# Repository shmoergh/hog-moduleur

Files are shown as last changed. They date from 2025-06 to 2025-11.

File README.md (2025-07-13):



# Hog Moduleur

Fully analog DIY-friendly modular synth. Project is under development.

Follow the progress on [shmoergh.com](https://www.shmoergh.com/hog-moduleur/) — consider [subscribing to the newsletter](https://www.shmoergh.com/hog-moduleur/#/portal/signup) to get the latest updates in your inbox.



## Modules

- [00 — Eurorack frame](https://github.com/shmoergh/hog-moduleur/tree/main/00-eurorack-frame)
- [01 — Power supply](https://github.com/shmoergh/hog-moduleur/tree/main/01-psu)

## License

Shmøergh Hog Moduleur © 2024

Hardware is licensed under [CC BY-NC 4.0](https://creativecommons.org/licenses/by-nc/4.0/)

Software is licensed under [MIT](https://opensource.org/license/mit).

Font used on PCBs: https://departuremono.com

Simulations made in [CircuitJS](https://www.falstad.com/circuit/circuitjs.html)

## Disclaimer

All electronic projects and designs presented on this web site, or associated web sites should be considered dangerous if not lethal if not used safely. When working on projects based on the designs on this site, use extreme care to ensure that you do not come into contact with mains AC voltages or high voltage DC. If you are not confident about working with mains voltages, or high voltages, or you are not legally allowed to work with mains voltages, or high voltages, you are advised not to attempt work on them. The author, host, and all people associated with these web pages disclaim any liability for damages should anyone be killed or injured while working on these projects, or projects based on these designs, or any other project or design presented on these web pages and any associated web pages. The author, host, and all people associated with these web pages also disclaim any liability for projects, or projects based on these designs, or any other project or design presented on these web pages and any associated web pages when used in such a way as to infringe relevant government regulations and by-laws.

All circuits, schematics, printed circuit board, panel design and associated data published on this site can be used for private use only.

We are not responsible for any errors in the PCB design or the parts list. All responsibility for ordering PCBs, components, and assembly services rests solely with you.

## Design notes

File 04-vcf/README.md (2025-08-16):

# Hog Moduleur / VCF

Dual mode Eurorack compatible diode filter based on the famous Synthacon Steiner-Parker circuit.

## Features

- Classic diode filter with extremely drippy character
- Low pass and high pass filter inputs
- Fine-tunable maximum resonance control — can go smooth to crazy
- Two external CV inputs with logarithmic attenuverters
- Optional EMC shielding to isolate external noise
- Separate core and UI PCBs for reusability and custom UI builds
- Gerber files for JLCPCB order
- Designed from very common electronic components

## Photos


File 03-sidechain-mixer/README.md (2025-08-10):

# Hog Moduleur / Sidechain Mixer

4 channel Eurorack compatible mixer and sidechain compressor.

## Features

- 4 input audio or CV mixer (DC coupled)
- Channel 4 can be used as the control input for a VCA based sidechain compressor that acts on the output mix. Channel 4 can be individually added to the output mix or can remain silent, while the compressor still operates.
- Gain control for channel 4 which allows to amplify line level signals to Eurorack level, allowing to mix external instruments with Eurorack sound sources
- Dedicated output volume control
- Separate core and UI PCBs for reusability and custom UI builds
- Gerber files for JLCPCB order
- Designed from very common electronic components

## Status

**MODULE IS IN EXPERIMENTAL STATE! ASSUME WEIRD BEHAVIORS** 

More info in KiCad files.

## Photos



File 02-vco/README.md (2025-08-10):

# Hog Moduleur / VCO

Eurorack compatible VCO.

## Features

- Raw saw generator with classic waveshaper circuits. Triangle, saw and square outputs
- Sub oscillator and noise circuit (can be selected with a jumper)
- Pulse width voltage control for square wave
- High precision over about 10 octaves
- Hard sync input
- FM input
- Two temperature compensation options for flexible DIY build (one is THT only)
- Separate core and UI PCBs for reusability and custom UI builds
- Gerber files for JLCPCB order
- Designed from very common electronic components

## Photos



**IN PROGRESS**

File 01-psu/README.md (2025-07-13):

# Hog Moduleur / PSU – ±12V Eurorack Power Supply

This is the power supply unit for the Hog Moduleur, but it can be used in any Eurorack setup.

## 🐷 Features

- ±12V power. Works with any of the following Mean Well regulators:
    - [NSD10-12D12](https://mou.sr/3ZpECrS)
    - [DKM10A-12](https://mou.sr/450kLTV)
    - [DKMW20F-12](https://mou.sr/44G5aaH)
    - [DKMW30F-12](https://mou.sr/450gwaT)
- Requires **center positive** 12V DC input
- Breakable board: PSU and connector section can be separated (cut) for flexible mounting
- Built in DC barrel jack input and power switch
- Optional +/- input headers for off-board DC & switch placement. Just make sure you know what you're doing if you're using it.
- Designed for small Eurorack cases and standalone synth builds. Output current depends on the regulator used (see above).
- Open source hardware

## 🛠️ How to Build

- Gerber files for JLCPCB ordering are in the [`electronics/production`](./electronics/production) folder
- BOM is also in the [`electronics/production`](./electronics/production) folder. All components are available at Mouser
- Use the KiCad schematic and PCB layout for soldering reference
- **Before connecting any modules**, always measure the output voltages to confirm ±12V is stable

⚠️ This is a DIY-friendly project but assumes you know how to solder, read schematics, and handle basic electronics safely.

## 📷 Photos

CleanShot 2025-07-13 at 12 34 50@2x



## 🧪 License

Open source licensed under [CC BY-NC 4.0](https://creativecommons.org/licenses/by-nc/4.0/).

Feel free to fork, build, and tweak.

[Disclaimer](https://github.com/shmoergh/hog-moduleur)

---

🐖 [Shmøergh](https://shmoergh.com) — Fucking cool electronic instruments from Budaørs, HU.

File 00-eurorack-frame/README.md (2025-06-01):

# Hog Moduleur / Eurorack Frame

Extensible, 3D printable enclosure/frame designed for synth development in Eurorack format. 

## Components

1. **Rail** — designed to be parametric, meaning that you can print it in any length just by adjusting the Y dimension in the 3D slicer software. It accepts standard M3 square nuts and M3x8 bolts.
2. **Connector** — join the stands to the rails vertically, and they also link rails to each other horizontally.
3. **Stands** — slanted at a 10° angle. Since they are not permanently coupled with the rails, it's easy to design and swap in other stand styles (e.g. flat) if needed.



## Assembly

No extra hardware is needed for full assembly.

1. Slide connectors to upper and lower slots of first stand
2. Slide in rails to first stand
3. Connect second stand and rails with connectors 



eurorack-frame-24hp

Default width of the rails is 24HP but it can be set directly in the slicer. Once we need more space it'll be very easy to extend the system to 48HP and further, just by offsetting the connectors and attaching new rails and stands.

eurorack-frame-48hp

## Printing instructions

When printing any of these components, choose the sides as the base in your slicer app. This allows printing without support which results in a much cleaner and stronger print, plus you can change the width (height) of the components as you wish, directly in the slicer.

CleanShot-2025-05-25-at-18 59 58@2x

## Mounting Eurorack modules

The rails welcome standard M3 square nuts and you can use M3x8 screws to mount max 2mm thick panels. Use M3x10 screws for thicker panels.

## Photos




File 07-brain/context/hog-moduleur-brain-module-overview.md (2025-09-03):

# Hog Moduleur "Brain" module

## About

We're building a module for a synthesizer, called Brain. It is a universal digital module in a Eurorack synthesizer with multipurpose inputs and outputs which allows users to write their own firmware. Additionally we're going to provide some basic modules and probably an SDK for it so that it's easy to get started.

## Features

Brain is based on the Raspberry Pi Pico. It's a universal digital module for Eurorack synths with flexible inputs and outputs.
- 2 analog inputs for CV and audio signals using 2 of the the Pico's ADCs
- 2 analog outputs which uses an MCP4822 DAC. The output of the DAC can be programmatically AC or DC coupled, using a CD4053 IC.
- 1 pulse input, using digital GPIO, preceded by a transistor switch (for safety)
- 1 pulse output, using digital GPIO with a simple transistor switch
- 1 dedicated MIDI input. This input is not universal because MIDI requires special input circuitry

Additionally there are some controls on the UI:
- 3 potmeters, multiplexed, using the third ADC of the Pico
- 2 pushbuttons
- 6 LEDs. The power for the LEDs are taken from the external power supply (using transistors) because of the Pico's limited power capabilities. The LEDs brightness can be set with PWM output from the Pico

As the Pico and Pico2 are pin compatible, the newer version can be used for heavier programs like effects or DSP.

## Code

Code can be flashed to the Pico using the normal procedure of holding the dedicated button while plugging the pico in a computer. Then the Pico appears as a drive which can accept firmware files.

## Factory programs

The first (default) factory program will be a MIDI to CV converter, as the rest of the synth works with control voltage. Later we'll work on a sequencer/arpeggiator, delay or reverb, external sound sources, basic drum machine and so on.

The factory programs are all written in C++ using the Pico SDK.

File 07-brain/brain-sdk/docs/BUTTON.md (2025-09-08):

# BUTTON Component

## Overview
The BUTTON component provides an interface for pushbutton inputs in the Hog Moduleur Brain module. It handles debouncing, state tracking, and event callbacks for button presses and releases.

## Features
- Debounced button input using Pico GPIO
- Event-driven: supports callbacks for press/release
- Polling via `update()` method for main loop integration
- Configurable for different GPIO pins

## Usage
1. **Initialization**: Create a `Button` instance, specifying the GPIO pin.
2. **Polling**: Call `update()` regularly in your main loop.
3. **Callbacks**: Register callback functions for press/release events.

## Example
```cpp
#include "brain-ui/button.h"

brain::ui::Button myButton(5); // GPIO 5
myButton.setPressCallback([](){
    // Handle press
});
myButton.setReleaseCallback([](){
    // Handle release
});

while (true) {
    myButton.update();
    // ...other code...
}
```

## Notes
- Designed for use with mechanical pushbuttons.
- Debounce logic is optimized for embedded use.
- Avoid long operations in callbacks.

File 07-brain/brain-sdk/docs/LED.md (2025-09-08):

# LED Component

## Overview
The LED component manages individual LEDs in the Hog Moduleur Brain module, supporting brightness control via PWM and event-driven blinking.

## Features
- Controls LED state (on/off)
- Adjustable brightness using Pico PWM
- Supports blinking with configurable duration
- Event callback for blink completion

## Usage
1. **Initialization**: Create an `Led` instance, specifying the GPIO pin and PWM channel.
2. **Control**: Use methods to set brightness, turn on/off, or start a blink.
3. **Polling**: Call `update()` in the main loop for blink timing.
4. **Callbacks**: Register a callback for blink completion if needed.

## Example
```cpp
#include "brain-ui/led.h"

brain::ui::Led statusLed(10, 2); // GPIO 10, PWM slice 2
statusLed.setBrightness(128); // 50% brightness
statusLed.blink(500); // Blink for 500 ms
statusLed.setBlinkCallback([](){
    // Blink finished
});

while (true) {
    statusLed.update();
}
```

## Notes
- Designed for transistor-driven LEDs (Eurorack compatible)
- Avoid blocking operations in callbacks
- Multiple LEDs can be managed independently

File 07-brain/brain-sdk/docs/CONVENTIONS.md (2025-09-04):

# Brain SDK – C/C++ Conventions (Google Style, Embedded-friendly)

> Scope: All code in `brain-sdk/` (`lib/*`, `programs/*`).
> Baseline: Google C++ Style Guide (naming, formatting, includes) with embedded tweaks.

---

## 0) TL;DR Checklist
- 4-space indent, max 100 cols, UTF-8, Unix newlines.
- Filenames: `lower_case_with_underscores.{h,cc,cpp}`.
- Folder names: `kebab-case` (e.g., `brain-io`, `brain-dsp`).
- Types/classes/enums: `PascalCase`.
- Functions: `PascalCase`.
- Variables: `lower_case_with_underscores`; class members end with `_`.
- Constants: `kPascalCase`.
- Macros: `ALL_CAPS_WITH_UNDERSCORES` (avoid; prefer `constexpr`/`enum`).
- No exceptions, no RTTI by default. No dynamic allocation in ISRs.
- `const` and `constexpr` aggressively. Prefer `enum class` over `#define`.
- One `#include` per line. Order: C system → C++ std → third-party → project.
- Headers are self-contained & guarded. `.cc/.cpp` mirrors header order.
- Public APIs documented with brief Doxygen comments.

---

## 1) File Layout & Naming
- **Folders**: use kebab-case → `lib/brain-io/`, `lib/brain-dsp/`.
- **Files**: `lower_case_with_underscores.h` / `.cc` (or `.cpp`).
- **One module per pair**: `brain-io/gpio_driver.h` ↔ `brain-io/gpio_driver.cc`.
- **No mega-files**: prefer small, testable units.

**Header guard** (prefer `#pragma once` for brevity):
```cpp
#pragma once
// or, if guards required:
// #ifndef BRAIN_IO_GPIO_DRIVER_H_
// #define BRAIN_IO_GPIO_DRIVER_H_
// ...
// #endif  // BRAIN_IO_GPIO_DRIVER_H_
```

---

## 2) Includes & Dependencies
Order in both headers and sources:
1. C system headers (`<stdint.h>`, `<stddef.h>`)
2. C++ standard (`<array>`, `<span>`, `<optional>`)
3. Pico/3rd-party (`<pico/stdlib.h>`, `hardware/gpio.h`)
4. Project headers (`"brain-io/gpio_driver.h"`)

One include per line; no wildcard includes. Prefer forward declarations in headers where possible.

---

## 3) Formatting
- **Indent**: 4 spaces; **Line length**: 100.
- **Braces**: K&R style.
```cpp
if (ready) {
	DoThing();
} else {
  	HandleError();
}
```
- **Namespace**: wrap entire file; avoid anonymous namespaces in headers.
```cpp
namespace brain::io {
// ...
}  // namespace brain::io
```

---

## 4) Naming
- **Namespaces**: `lower_case` (e.g., `brain::io`).
- **Types / Classes / Structs / Enums**: `PascalCase` (e.g., `AdcSampler`).
- **Functions & Methods**: `PascalCase` (e.g., `Init()`, `ReadChannel()`).
- **Variables**: `lower_case_with_underscores` (`sample_rate_hz`).
  - **Data members**: `trailing_underscore_` (e.g., `gpio_`).
- **Constants**: `kPascalCase` (`kMaxChannels`).
- **Macros**: `ALL_CAPS_WITH_UNDERSCORES` (use sparingly).
- **Aliases**: `using Sample = uint16_t;` (avoid `typedef` in new code).

---

## 5) Language Use
### C++
- **C++17+** (or project default). Prefer `<array>`, `<span>`, `<optional>`, `<chrono>`.
- **No exceptions / no RTTI** by default (size & determinism). Use `Status` returns.
- Prefer **`enum class`**; avoid unscoped enums.
- Prefer **`constexpr`** & **`const`** over macros; **`static`** for internal linkage.
- RAII for HW resources when feasible (GPIO claim/release), but keep ISRs free of heavy constructs.

### C (when used)
- Follow same formatting; `snake_case` for functions/vars is acceptable in pure-C modules.
- Use fixed-width integers from `<stdint.h>`.

---

## 6) APIs & Headers
- Headers are **self-contained** (compile on their own).
- Forward-declare where practical; don’t `#include` what you don’t use.
- Public API gets a brief Doxygen block:
```cpp
/// Samples N channels via a 74HC4051 into the Pico ADC.
/// Blocking; ~200 µs per channel typical.
/// @param channels logical channel indices [0..2]
/// @return last sampled value in 12-bit right-aligned format.
uint16_t SampleOnce(int channel);
```

---

## 7) Error Handling & Logging
- Return `bool` / small `Status` enums for expected errors; no exceptions.
- For fatal HW config errors in bring-up/demo code, `assert()` is acceptable (not in library hot paths).
- Logging:
  - Default to **UART stdio** (`pico_enable_stdio_uart(... 1)`).
  - Use minimal `fprintf(stderr, ...)`/`printf()` in libraries; let programs decide verbosity.

---

## 8) Embedded Rules (Pico/RP2040)
- **ISRs**: `static inline` where sensible; **no malloc/new**, no `printf`, keep <50 µs.
- **Volatile** only for MMIO or truly shared flags; pair with memory barriers when needed.
- **Concurrency**: prefer RP2040 primitives (IRQ disable windows, multicore queues, spinlocks) with brief critical sections.
- **Timing**: use `absolute_time_t` / `busy_wait_us()` from pico-time; avoid ad-hoc loops.
- **GPIO**: configure once in init; document pin ownership in module comments.
- **DMA/PWM/ADC**: place registers/config in one module; avoid cross-module control.

---

## 9) Tests & Examples
- Unit tests for pure logic (host-buildable) go under `tests/` (future).
- Hardware demos live in `programs/<name>/`.
- Keep examples tiny: one concept per example.

---

## 10) CMake Conventions
- Targets mirror file names: `brain-io`, `adc-sampler`, etc.
- Libraries default to **`INTERFACE`** if header-only; otherwise `STATIC`.
- All executables link `pico_stdlib` and only the libs they need.
- Stdio defaults (for picoprobe):
  ```cmake
  pico_enable_stdio_usb(<target> 0)
  pico_enable_stdio_uart(<target> 1)
  ```
- Add UF2 outputs:
  ```cmake
  pico_add_extra_outputs(<target>)
  ```

---

## 11) Comments & Documentation
- Prefer short, clear comments explaining *why*, not *what*.
- File header (top 6 lines): one-sentence purpose, dependencies, hardware notes, author/owner.
- Use Doxygen for public APIs; keep private helpers undocumented unless non-obvious.

---

## 12) Sample Skeleton

```cpp
// adc-sampler.h
#pragma once
#include <cstdint>
namespace brain::io {

class AdcSampler {
 public:
  bool Init();                   // config ADC + mux GPIOs
  uint16_t SampleChannel(int channel);  // 0..2

 private:
  void SelectMux(int channel);
  uint16_t ReadAdcOnce();

  int adc_channel_ = 0;
};

}  // namespace brain::io
```

```cpp
// adc-sampler.cc
#include "brain-io/adc-sampler.h"
#include "pico/stdlib.h"
#include "hardware/adc.h"

namespace brain::io {

bool AdcSampler::Init() {
  adc_init();
  // configure GPIOs, etc.
  return true;
}

uint16_t AdcSampler::SampleChannel(int channel) {
  SelectMux(channel);
  sleep_us(10);     // settle
  (void)ReadAdcOnce(); // throw-away
  return ReadAdcOnce();
}

void AdcSampler::SelectMux(int channel) {
  // drive S0/S1, keep S2 low
}

uint16_t AdcSampler::ReadAdcOnce() {
  return adc_read();
}

}  // namespace brain::io
```

---

## 13) Things to Avoid
- Global mutable state (except tightly-scoped singletons for HW where necessary).
- Hidden work in constructors; prefer `Init()` returning `bool`.
- Long lambdas or templates in embedded hot paths (code size bloat).
- Overuse of macros; prefer `constexpr`, `inline`, and typed enums.

---

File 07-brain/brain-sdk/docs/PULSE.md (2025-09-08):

# PULSE Component

## Overview
The PULSE component provides digital pulse input and output handling for the Hog Moduleur Brain module. It supports edge detection, debouncing, and event callbacks for pulse events.

## Features
- Handles pulse input (e.g., clock, trigger) via GPIO
- Supports pulse output (e.g., gate, trigger)
- Edge detection (rising/falling)
- Debounce logic for input pulses
- Event-driven: callbacks for pulse events

## Usage
1. **Initialization**: Create a `Pulse` instance, specifying the GPIO pin and direction (input/output).
2. **Polling**: Call `update()` in the main loop for input edge detection.
3. **Control**: For output, use methods to set or trigger pulses.
4. **Callbacks**: Register callbacks for pulse events (input only).

## Example
```cpp
#include "brain-io/pulse.h"

brain::io::Pulse clockIn(6, true); // GPIO 6, input
clockIn.setRisingCallback([](){
    // Clock pulse detected
});

brain::io::Pulse gateOut(7, false); // GPIO 7, output
gateOut.trigger(); // Send pulse

while (true) {
    clockIn.update();
}
```

## Notes
- Designed for Eurorack pulse signals (5V logic)
- Debounce logic is optimized for fast clocks
- Avoid blocking operations in callbacks

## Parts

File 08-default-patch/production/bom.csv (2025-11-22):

Designator | Footprint | Quantity | Value | LCSC Part #
JP1, JP10, JP11, JP12, JP13, JP2, JP3, JP4, JP5, JP6, JP7, JP8, JP9 | SolderJumper-2_P1.3mm_Bridged_RoundedPad1.0x1.5mm | 13 | Jumper_2_Bridged
J_ENV_VCA1, J_ENV_VCA2, J_FILTER1, J_MIXER1, J_UTILS_OUT1 | PinHeader_2x06_P2.54mm_Vertical | 5 | Conn_01x06
J_VCO1, J_VCO2 | PinHeader_2x07_P2.54mm_Vertical | 2 | Conn_01x07

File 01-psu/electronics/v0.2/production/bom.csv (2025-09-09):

Designator | Footprint | Quantity | Value | LCSC Part #
D1, D3, D4 | LED_D3.0mm | 3 | LED
D2 | D_DO-41_SOD81_P7.62mm_Horizontal | 1 | 1N4001
IC1 | Converter_DCDC_MeanWell_NSD10_DKMW_THT | 1 | ISOLATED_DC-DC_CONV
J1 | BarrelJack_Wuerth_6941xx301002 | 1 | Barrel_Jack_Switch
J2, J3, J4, J5 | IDC-Header_2x08_P2.54mm_Horizontal | 4 | Conn_02x08_Odd_Even
R1, R2, R3 | R_Axial_DIN0207_L6.3mm_D2.5mm_P7.62mm_Horizontal | 3 | 1k
S1 | SW_PB400EEQR1BLK | 1 | PB400EEQR1BLK

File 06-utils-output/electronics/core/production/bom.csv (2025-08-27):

Designator | Footprint | Quantity | Value | LCSC Part #
C1, C10, C11, C12, C13, C2, C3, C4, C5, C6 | 0603 | 10 | 100n | C14663
C14 | CP_Elec_5x5.4 | 1 | 10u | C4747971
C15 | 0603 | 1 | 100p | C14858
C16, C17 | C_Rect_L7.2mm_W2.5mm_P5.00mm_FKS2_FKP2_MKS2_MKP2 | 2 | 100n (foil)
C18 | C_Rect_L7.2mm_W2.5mm_P5.00mm_FKS2_FKP2_MKS2_MKP2 | 1 | 1n (foil)
C7 | C_Rect_L7.0mm_W2.5mm_P5.00mm | 1 | 22n-47n (foil)
C8, C9 | CP_Elec_6.3x7.7 | 2 | 100u | C2836437
D1, D2 | D_SOD-323 | 2 | 1N5817 | C5190152
D15, D16, D3, D4 | D_SOD-123 | 4 | 1N4148 | C81598
D_LIM_N1 | LED_D3.0mm | 1 | Red LED
D_LIM_P1 | LED_D5.0mm | 1 | Red LED
J1 | PinHeader_2x06_P2.54mm_Vertical | 1 | Conn_02x06_Odd_Even
J2 | PinHeader_2x03_P2.54mm_Vertical | 1 | Conn_02x03_Odd_Even
J3 | PinHeader_1x02_P2.54mm_Vertical | 1 | Conn_01x02
J4 | PinHeader_2x04_P2.54mm_Vertical | 1 | Conn_02x04_Odd_Even
J5 | PinHeader_2x02_P2.54mm_Vertical | 1 | Conn_02x02_Odd_Even
J6 | PinHeader_2x05_P2.54mm_Vertical | 1 | Conn_02x05_Odd_Even
J7 | IDC-Header_2x05_P2.54mm_Horizontal | 1 | Conn_02x05_Odd_Even
Q2 | TO-92_Inline_Wide | 1 | 2N3819
Q4 | SOT-23 | 1 | BC848 | C458985
R1 | 0603 | 1 | 33k | C4216
R10, R18, R26, R27, R29, R7 | 0603 | 6 | 10k | C25804
R11, R20 | 0603 | 2 | 4.7k | C23162
R12 | 0603 | 1 | 150 | C22808
R13, R17, R25, R28, R30 | 0603 | 5 | 1k | C21190
R14, R15 | 0603 | 2 | 100 | C22775
R16 | 0603 | 1 | 1M | C22935
R19, R2, R21, R22, R23, R3, R4, R5, R6 | 0603 | 9 | 100k | C25803
R24 | 0603 | 1 | 22k | C31850
R8, R9 | 0603 | 2 | 47k | C25819
RV_HEADPHONE_LIM1 | Potentiometer_ACP_CA6-H2,5_Horizontal | 1 | 100k
RV_LINE_OUT_LVL1 | Potentiometer_ACP_CA6-H2,5_Horizontal | 1 | 10k
U1, U2, U3, U5 | SOIC-8_3.9x4.9mm_P1.27mm | 4 | TL072 | C6961
U4 | SOIC-8_3.9x4.9mm_P1.27mm | 1 | NE5532 | C7426

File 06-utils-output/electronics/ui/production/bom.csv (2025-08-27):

Designator | Footprint | Quantity | Value | LCSC Part #
D1 | D_SMA | 1 | SMAJ5.0CA
D_DRIVE1, D_LFO1 | LED_D3.0mm | 2 | Red LED
D_DRIVE_FROM_CORE1 | PinSocket_1x02_P2.54mm_Vertical | 1 | Red LED
J1 | PinSocket_2x03_P2.54mm_Vertical | 1 | Conn_02x03_Odd_Even
J2 | PinSocket_2x04_P2.54mm_Vertical | 1 | Conn_02x04_Odd_Even
J3 | PinSocket_2x02_P2.54mm_Vertical | 1 | Conn_02x02_Odd_Even
J4 | PinSocket_1x02_P2.54mm_Vertical | 1 | Conn_01x02
J5 | PinSocket_1x06_P2.54mm_Vertical | 1 | Conn_01x06
J6 | PinSocket_2x05_P2.54mm_Vertical | 1 | Conn_02x05_Odd_Even
J_CRUSH_IN1, J_CRUSH_OUT1, J_CRUSH_TRIG1, J_LFO_SQR1, J_LFO_TRI1, J_MAIN_IN1, J_MAIN_OUT1 | Jack_3.5mm_QingPu_WQP-PJ398SM_Vertical_CircularHoles | 7 | PJ398SM
Q1 | TO-92_Inline_Wide | 1 | 2N3904
R1 | R_Axial_DIN0207_L6.3mm_D2.5mm_P7.62mm_Horizontal | 1 | 47k
R2 | R_Axial_DIN0207_L6.3mm_D2.5mm_P7.62mm_Horizontal | 1 | 1k
R3 | R_Axial_DIN0207_L6.3mm_D2.5mm_P7.62mm_Horizontal | 1 | 150-220
RV_CRUSH1 | Potentiometer_Bourns_Single-PTV09A | 1 | 1M
RV_DRIVE1 | Potentiometer_Bourns_Single-PTV09A | 1 | 100k
RV_LFO_AMOUNT1 | Potentiometer_Bourns_Dual-PTV112-4 | 1 | A20k
RV_LFO_RATE1 | Potentiometer_Bourns_Single-PTV09A | 1 | A100k
RV_MAIN_VOLUME1 | Potentiometer_Bourns_Single-PTV09A | 1 | A10k

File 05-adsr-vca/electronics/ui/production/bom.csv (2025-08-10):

Designator | Footprint | Quantity | Value | LCSC Part #
D1 | LED_D3.0mm | 1 | D
J1, J3, J6, J8 | PinSocket_2x03_P2.54mm_Vertical | 4 | Conn_02x03_Odd_Even
J4 | PinSocket_1x02_P2.54mm_Vertical | 1 | Conn_01x02
J5 | PinSocket_1x06_P2.54mm_Vertical | 1 | Conn_01x06
JP_DEFAULT_ENV_TO_VCA1 | PinHeader_1x02_P2.54mm_Horizontal | 1 | Jumper_2_Open
J_ENV_OUT1, J_GATE1, J_VCA_CV1, J_VCA_IN1, J_VCA_OUT1 | Jack_3.5mm_QingPu_WQP-PJ398SM_Vertical_CircularHoles | 5 | PJ398SM
RV_ATTACK1, RV_DECAY1, RV_RELEASE1 | Potentiometer_Bourns_Single-PTV09A | 3 | A500k
RV_SUSTAIN1 | TRIM_PTA4543-2015DPB103 | 1 | 10k

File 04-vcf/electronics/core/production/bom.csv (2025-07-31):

Designator | Footprint | Quantity | Value | LCSC Part #
C1, C15, C16, C2, C3, C4, C5, C6, C8, C9 | 0603 | 10 | 100n | C14663
C10, C12, C14 | C_Rect_L7.0mm_W2.5mm_P5.00mm | 3 | 1n (Foil)
C11 | CP_Elec_4x5.7 | 1 | 2.2u | C249889
C13, C17, C21, C22 | CP_Elec_6.3x7.7 | 4 | 100u | C2836437
C18 | C_Rect_L7.0mm_W3.5mm_P5.00mm | 1 | 470n (foil)
C19 | C_Rect_L7.0mm_W4.5mm_P5.00mm | 1 | 1u (Foil)
C20 | CP_Elec_4x5.4 | 1 | 10u | C3343
C7 | 0603 | 1 | 10n | C57112
D1, D10, D2, D3, D4, D5, D6, D7, D8, D9 | D_SOD-123 | 10 | 1N4148 | C81598
D11, D12 | D_SOD-323 | 2 | 1N5817 | C5190152
J1 | PinHeader_1x06_P2.54mm_Vertical | 1 | Conn_01x06
J2 | PinHeader_2x04_P2.54mm_Vertical | 1 | Conn_02x04_Counter_Clockwise
J3 | PinHeader_2x02_P2.54mm_Vertical | 1 | Conn_02x02_Counter_Clockwise
J6 | PinHeader_2x03_P2.54mm_Vertical | 1 | Conn_02x03_Odd_Even
J7 | PinHeader_1x02_P2.54mm_Vertical | 1 | Conn_01x02
J8 | IDC-Header_2x05_P2.54mm_Horizontal | 1 | Conn_02x05_Odd_Even
Q1 | SOT-363_SC-70-6 | 1 | BC847BS | C5380687
R1 | 0603 | 1 | 20k | C4184
R10 | 0603 | 1 | 200k | C25811
R11 | 0603 | 1 | 180k | C3016400
R12 | 0603 | 1 | 2.7k | C13167
R13, R22 | R_Axial_DIN0207_L6.3mm_D2.5mm_P7.62mm_Horizontal | 2 | 2k
R14 | 0603 | 1 | 2.2k | C4190
R15 | 0603 | 1 | 33k | C4216
R16 | 0603 | 1 | 100 | C22775
R17 | 0603 | 1 | 390 | C23151
R18, R19, R23, R32 | 0603 | 4 | 1k | C21190
R20 | 0603 | 1 | 3.9k | C23018
R21 | 0603 | 1 | 200 | C8218
R24, R27 | 0603 | 2 | 1M | C22935
R25 | 0603 | 1 | 22k | C31850
R26, R9 | 0603 | 2 | 47k | C25819
R28 | 0603 | 1 | 220k | C22961
R29, R4, R6, R8 | 0603 | 4 | 10k | C25804
R30, R31 | 0603 | 2 | 100k | C25803
R7 | 0603 | 1 | 56k | C23206
RV_BALANCE1 | Potentiometer_ACP_CA6-H2,5_Horizontal | 1 | 1k
RV_MAX_RESO1 | Potentiometer_ACP_CA6-H2,5_Horizontal | 1 | 100k
U1, U2, U3, U4 | SOIC-8_3.9x4.9mm_P1.27mm | 4 | TL072 | C6961

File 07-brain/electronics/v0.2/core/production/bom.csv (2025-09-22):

Designator | Footprint | Quantity | Value | LCSC Part #
C1 | CP_Elec_4x5.4 | 1 | 10u | C46550410
C10, C11 | 0603 | 2 | 22p | C1653
C12, C13, C14, C15, C16, C17, C3, C6, C7, C8, C9 | 0603 | 11 | 100n | C14663
C18 | 0603 | 1 | 10u | C19702
C2 | 0603 | 1 | 330n | C188679
C4, C5 | CP_Elec_6.3x7.7 | 2 | 100u | C2836437
D1, D2, D3 | D_SOD-323 | 3 | 1N5817 | C5190152
D4 | SOT-23 | 1 | BAT54 | C22466368
D5, D6 | SOT-23 | 2 | BAT54S | C7420333
J1, J4, J8 | PinHeader_2x03_P2.54mm_Vertical | 3 | Conn_02x03_Odd_Even
J10, J5, J9, J_DEV1 | PinHeader_1x02_P2.54mm_Vertical | 4 | Conn_01x02
J11 | PinHeader_1x01_P2.54mm_Vertical | 1 | Conn_01x01
J13 | PinHeader_1x03_P2.54mm_Vertical | 1 | Conn_01x03
J2, J3 | PinHeader_2x02_P2.54mm_Vertical | 2 | Conn_02x02_Odd_Even
J6 | IDC-Header_2x05_P2.54mm_Horizontal | 1 | Conn_02x05_Odd_Even
J7 | PinHeader_2x05_P2.54mm_Vertical | 1 | Conn_02x05_Odd_Even
J_USB_C_EXTENSION1 | USB_C_Receptacle_HRO_TYPE-C-31-M-12 | 1 | USB_C_Receptacle_USB2.0_16P | C165948
Q1, Q3, Q6, Q7 | SOT-23 | 4 | MMBT3904 | C20526
R1, R14, R15, R16, R17, R18, R19, R20, R21, R24, R26, R30, R31, R32, R33 | 0603 | 15 | 100k | C25803
R10, R11 | 0603 | 2 | 68k | C23231
R12, R13, R22, R23, R34, R35 | 0603 | 6 | 1k | C21190
R2 | 0603 | 1 | 3.3k | C22978
R25, R27 | 0603 | 2 | 120k | C25808
R28, R29 | 0603 | 2 | 33k | C4216
R3, R7 | 0603 | 2 | 10k | C25804
R36, R37 | 0603 | 2 | 5.1k | C23186
R4 | 0603 | 1 | 7.5k | C23234
R5 | 0603 | 1 | 2.2k | C4190
R6 | 0603 | 1 | 120 | C22787
R8, R9 | 0603 | 2 | 47k | C25819
SW1 | SW_Tactile_SKHH_Angled | 1 | SW_SPST
U1 | TO-220-3_Horizontal_TabDown | 1 | LM7805_TO220
U10 | SOIC-16_3.9x9.9mm_P1.27mm | 1 | 74HC4051 | C9386
U2 | SOP-8_6.605x9.655mm_P2.54mm | 1 | 6N137 | C92651
U3 | RaspberryPi_Pico_Common_Unspecified | 1 | Pico
U4, U5, U8, U9 | SOIC-8_3.9x4.9mm_P1.27mm | 4 | TL072 | C6961
U6 | SOIC-8_3.9x4.9mm_P1.27mm | 1 | MCP4822 | C623653
U7 | SOIC-16_3.9x9.9mm_P1.27mm | 1 | 74HC4053B | C5647

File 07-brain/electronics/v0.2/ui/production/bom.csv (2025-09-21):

Designator | Footprint | Quantity | Value | LCSC Part #
D1, D2, D3, D4, D5, D6 | LED_D3.0mm | 6 | LED
J1, J5, J8 | PinSocket_2x03_P2.54mm_Vertical | 3 | Conn_02x03_Odd_Even
J2, J3 | PinSocket_1x02_P2.54mm_Vertical | 2 | Conn_01x02
J4, J6 | PinSocket_2x02_P2.54mm_Vertical | 2 | Conn_02x02_Odd_Even
J7 | PinSocket_2x05_P2.54mm_Vertical | 1 | Conn_02x05_Odd_Even
J_AUDIO_CV_IN1, J_AUDIO_CV_IN2, J_AUDIO_CV_OUT1, J_AUDIO_CV_OUT2, J_PULSE_IN1, J_PULSE_OUT1 | Jack_3.5mm_QingPu_WQP-PJ398SM_Vertical_CircularHoles | 6 | PJ398SM
J_MIDI1 | Jack_3.5mm_QingPu_WQP-PJ398SM_Vertical_CircularHoles | 1 | PJ398SM-STEREO
Q1, Q2, Q3, Q4, Q5, Q6 | TO-92_Inline_Wide | 6 | 2N3904
R1, R2 | R_Axial_DIN0207_L6.3mm_D2.5mm_P7.62mm_Horizontal | 2 | 470
R10, R13, R14, R5, R6, R9 | R_Axial_DIN0207_L6.3mm_D2.5mm_P7.62mm_Horizontal | 6 | 1k
R11, R12, R3, R4, R7, R8 | R_Axial_DIN0207_L6.3mm_D2.5mm_P7.62mm_Horizontal | 6 | 47k | C25803
RV_POT1, RV_POT2, RV_POT3 | Potentiometer_Bourns_Single-PTV09A | 3 | 100k
U_BTN1, U_BTN2 | SPST_Circular_Pushbutton_LED | 2 | SW_SPST_Push_LED

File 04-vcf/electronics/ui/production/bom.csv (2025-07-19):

Designator | Footprint | Quantity | Value | LCSC Part #
C1, C2 | C_Disc_D5.0mm_W2.5mm_P2.50mm | 2 | C
J1 | PinSocket_2x03_P2.54mm_Vertical | 1 | Conn_02x03_Odd_Even
J2 | PinSocket_2x02_P2.54mm_Vertical | 1 | Conn_02x02_Counter_Clockwise
J4 | PinSocket_1x02_P2.54mm_Vertical | 1 | Conn_01x02
J5 | PinSocket_1x06_P2.54mm_Vertical | 1 | Conn_01x06
J6 | PinSocket_2x04_P2.54mm_Vertical | 1 | Conn_02x04_Odd_Even
J_CUTOFF1, J_CUTOFF2, J_HP1, J_LP1, J_OUT1 | Jack_3.5mm_QingPu_WQP-PJ398SM_Vertical_CircularHoles | 5 | PJ398SM
R1 | R_Axial_DIN0207_L6.3mm_D2.5mm_P7.62mm_Horizontal | 1 | 6.8k
R10, R11, R4, R5 | R_Axial_DIN0207_L6.3mm_D2.5mm_P7.62mm_Horizontal | 4 | 10k-1M
R12, R13, R14, R6, R7, R8, R9 | R_Axial_DIN0207_L6.3mm_D2.5mm_P7.62mm_Horizontal | 7 | 100k
R2 | R_Axial_DIN0207_L6.3mm_D2.5mm_P7.62mm_Horizontal | 1 | 3.3k
R3 | R_Axial_DIN0207_L6.3mm_D2.5mm_P7.62mm_Horizontal | 1 | 220k
RV_CUTOFF1, RV_CUTOFF2, RV_MAIN_CUTOFF1, RV_RESO1 | Potentiometer_Bourns_Single-PTV09A | 4 | 100k
RV_CUTOFF_BIAS1 | Potentiometer_ACP_CA6-H2,5_Horizontal | 1 | 10k
U1 | DIP-8_W7.62mm_LongPads | 1 | TL072

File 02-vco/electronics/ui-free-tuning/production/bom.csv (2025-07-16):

Designator | Footprint | Quantity | Value | LCSC Part #
J1 | PinSocket_1x04_P2.54mm_Vertical | 1 | Conn_01x04
J2 | PinSocket_2x05_P2.54mm_Vertical | 1 | Conn_02x05_Odd_Even
J3 | PinSocket_2x03_P2.54mm_Vertical | 1 | Conn_02x03_Odd_Even
J4 | PinSocket_1x02_P2.54mm_Vertical | 1 | Conn_01x02
J5 | PinSocket_2x02_P2.54mm_Vertical | 1 | Conn_02x02_Counter_Clockwise
J6 | PinSocket_1x06_P2.54mm_Vertical | 1 | Conn_01x06
JP1 | PinHeader_1x03_P2.54mm_Horizontal | 1 | Jumper_3_Open
JP2, JP3 | PinHeader_1x02_P2.54mm_Horizontal | 2 | Jumper_2_Open
J_CV1, J_EXTRA_OUT1, J_FM1, J_OUT1, J_PWM1, J_SYNC1 | Jack_3.5mm_QingPu_WQP-PJ398SM_Vertical_CircularHoles | 6 | PJ398SM
R1, R4, R5 | R_Axial_DIN0207_L6.3mm_D2.5mm_P7.62mm_Horizontal | 3 | ????
R2, R3, R6 | R_Axial_DIN0207_L6.3mm_D2.5mm_P7.62mm_Horizontal | 3 | 100k
R7, R8 | R_Axial_DIN0207_L6.3mm_D2.5mm_P7.62mm_Horizontal | 2 | 220k
RV_FINE1, RV_PWM1, RV_TUNE1 | Potentiometer_Bourns_Single-PTV09A | 3 | 100k
U1 | SR1712-0203 | 1 | 0203

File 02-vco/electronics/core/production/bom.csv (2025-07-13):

Designator | Footprint | Quantity | Value | LCSC Part #
C1, C13, C14, C15, C16, C17, C18, C2, C21, C22, C26, C27, C3, C4, C5, C6 | 0603 | 16 | 100n | C14663
C10 | 0603 | 1 | 22p | C1653
C11 | 0603 | 1 | 47p | C1671
C20 | 0603 | 1 | 33p | C1663
C23, C24 | CP_Elec_6.3x7.7 | 2 | 100u | C2836437
C28 | 0603 | 1 | 1u | C15849
C29 | C_Rect_L7.2mm_W3.5mm_P5.00mm_FKS2_FKP2_MKS2_MKP2 | 1 | 470n
C8 | 0603 | 1 | 100p | C14858
C9 | C_Rect_L7.2mm_W2.5mm_P5.00mm_FKS2_FKP2_MKS2_MKP2 | 1 | 2.2nF (foil)
D1, D2, D3 | D_SOD-123 | 3 | 1N4148 | C81598
D6, D7 | D_SOD-323 | 2 | 1N5817 | C5190152
J1 | PinHeader_1x04_P2.54mm_Vertical | 1 | Conn_01x04
J2 | PinHeader_2x05_P2.54mm_Vertical | 1 | Conn_02x05_Odd_Even
J3 | IDC-Header_2x05_P2.54mm_Horizontal | 1 | Conn_02x05_Odd_Even
J4 | PinHeader_1x02_P2.54mm_Vertical | 1 | Conn_01x02
J5 | PinHeader_2x03_P2.54mm_Vertical | 1 | Conn_02x03_Odd_Even
J6 | PinHeader_2x02_P2.54mm_Vertical | 1 | Conn_02x02_Counter_Clockwise
J8 | PinHeader_1x06_P2.54mm_Vertical | 1 | Conn_01x06
Q1 | SOT-363_SC-70-6 | 1 | BC847BS | C5380687
Q2 | SOT-23_Handsoldering | 1 | MMBT3906 | C7420354
Q3 | TO-92_Inline_Wide | 1 | J111
Q4 | SOT-23 | 1 | MMBFJ111 | C274688
Q5, Q7 | SOT-23 | 2 | MMBT5551 | C2145
Q6 | SOT-23 | 1 | BC847 | C8664
R1, R15, R18, R21, R25, R27, R28, R29, R30, R37, R38, R40, R41, R43, R5, R57 | 0603 | 16 | 100k | C25803
R10, R13, R4 | 0603 | 3 | 1M | C22935
R11, R9 | 0603 | 2 | 1.5k | C22843
R12 | 0603 | 1 | 510 | C23193
R14, R47 | 0603 | 2 | 10k | C25804
R16 | 0603 | 1 | 22k | C31850
R17, R2 | 0603 | 2 | 150k | C22807
R19 | 0603 | 1 | 330k | C23137
R20, R33 | 0603 | 2 | 2.2k | C4190
R22, R32, R45, R46 | 0603 | 4 | 47k | C25819
R23, R24 | 0603 | 2 | 15k | C22809
R26 | 0603 | 1 | 27k | C22967
R3, R6, R7, R8 | R_Axial_DIN0207_L6.3mm_D2.5mm_P7.62mm_Horizontal | 4 | See t.comp. table
R31, R34, R44, R56 | 0603 | 4 | 220k | C22961
R35 | 0603 | 1 | 2.2M | C22938
R36, R39 | 0603 | 2 | 240k | C4197
R42 | 0603 | 1 | 680 | C23228
R48 | 0603 | 1 | 56k | C23206
R50, R52, R53, R54, R55 | 0603 | 5 | 1k | C21190
RV_SAW_BIAS1 | Potentiometer_Bourns_3006P_Horizontal | 1 | 10k (prec)
RV_TRI_BIAS1, R_BIAS1 | Potentiometer_Bourns_3006P_Horizontal | 2 | 100k (prec)
R_HIFREQ1 | Potentiometer_Bourns_3006P_Horizontal | 1 | 2k (prec)
R_WIDTH1, R_WIDTH2 | Potentiometer_Bourns_3006P_Horizontal | 2 | See t.comp. table
TH1 | TO-92-2 | 1 | See t.comp. table
TH2 | 1206 | 1 | PTS120602B100RP100
U1, U2, U4, U5, U6, U7, U8 | SOIC-8_3.9x4.9mm_P1.27mm | 7 | TL072 | C6961
U3 | SOIC-8_3.9x4.9mm_P1.27mm | 1 | LM311 | C12597
U9 | SOIC-16_3.9x9.9mm_P1.27mm | 1 | CD4040BM96 | C353974

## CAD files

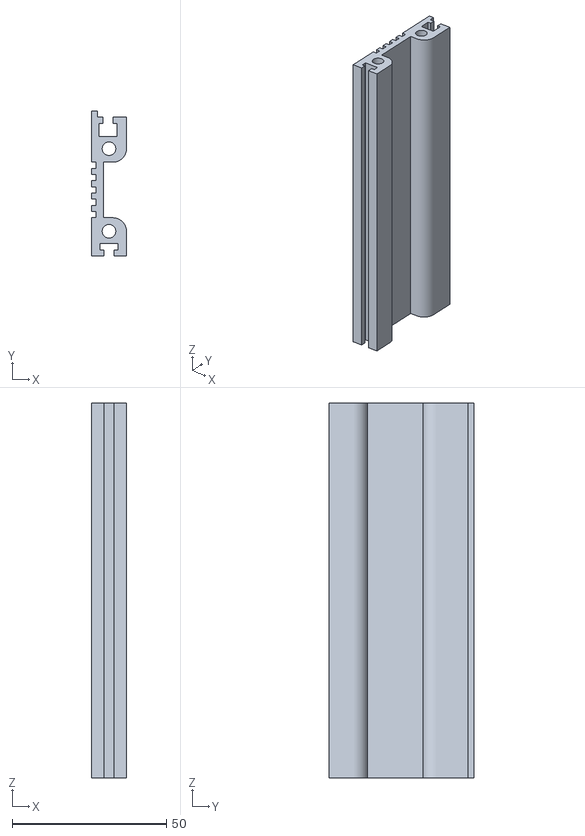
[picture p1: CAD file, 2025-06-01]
00-eurorack-frame/frame-rail.stl
11.4 x 47.0 x 121.6

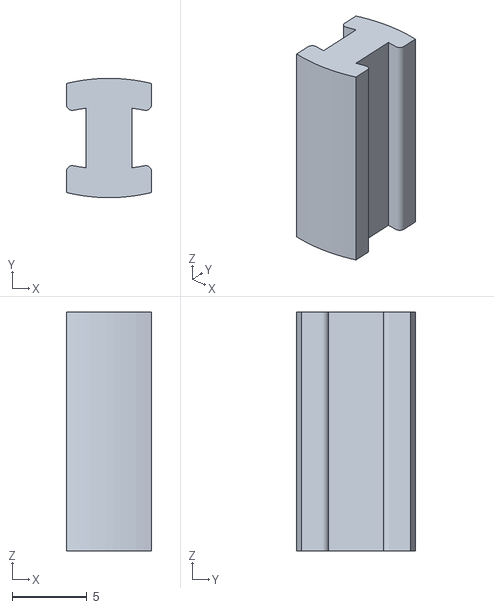
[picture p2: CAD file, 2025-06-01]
00-eurorack-frame/frame-connector.stl
5.70 x 7.98 x 16.0

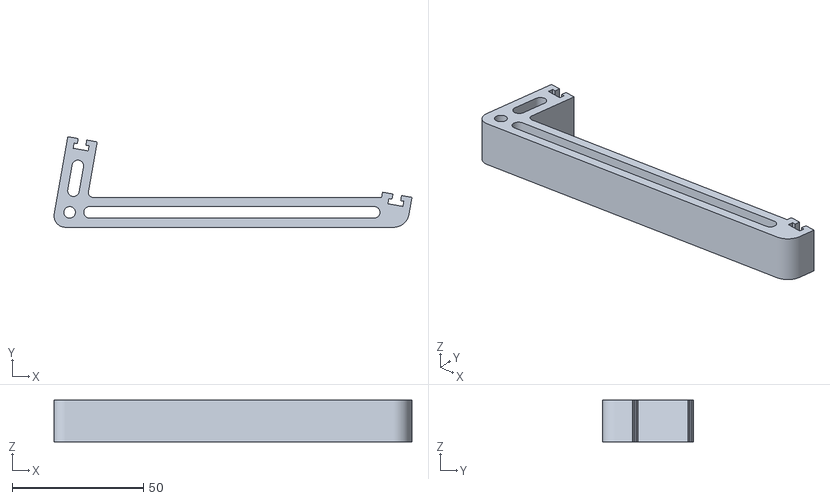
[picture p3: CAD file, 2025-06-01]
00-eurorack-frame/frame-stand.stl
136.6 x 34.6 x 16.0

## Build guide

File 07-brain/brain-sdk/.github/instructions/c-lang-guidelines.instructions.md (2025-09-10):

---
applyTo: '**'
---
# Project C/C++ Coding Guidelines (Google Style, Embedded-friendly)

> Baseline: Google C++ Style Guide (naming, formatting, includes) with embedded tweaks.

---

## File Layout & Naming
- **Folders**: use kebab-case → `lib/brain-io/`, `lib/brain-dsp/`.
- **Files**: use kebab-case → `brain-io.h` / `.cc` (or `.cpp`).
- **One module per pair**: `brain-io/gpio-driver.h` ↔ `brain-io/gpio-driver.cc`.
- **No mega-files**: prefer small, testable units.

**Header guard** (prefer `#ifndef` for brevity):
```cpp
#ifndef BRAIN_IO_GPIO_DRIVER_H
#define BRAIN_IO_GPIO_DRIVER_H
...
#endif  // BRAIN_IO_GPIO_DRIVER_H_
```

---

## Includes & Dependencies
Order in both headers and sources:
1. C system headers (`<stdint.h>`, `<stddef.h>`)
2. C++ standard (`<array>`, `<span>`, `<optional>`)
3. Pico/3rd-party (`<pico/stdlib.h>`, `hardware/gpio.h`)
4. Project headers (`"brain-io/gpio_driver.h"`)

One include per line; no wildcard includes. Prefer forward declarations in headers where possible.

---

## Formatting
- **Indent**: 4 spaces; **Line length**: 100.
- **Braces**: K&R style.
```cpp
if (ready) {
    doThing();
} else {
    handleError();
}
```
- **Namespace**: wrap entire file; avoid anonymous namespaces in headers.
```cpp
namespace brain::io {
// ...
}  // namespace brain::io
```

---

## Naming
- **Namespaces**: `lower_case` (e.g., `brain::io`).
- **Types / Classes / Structs / Enums**: `PascalCase` (e.g., `AdcSampler`).
- **Functions & Methods**: `camelCase` (e.g., `init()`, `readChannel()`).
- **Variables**: `lower_case_with_underscores` (`sample_rate_hz`).
  - **Data members**: `trailing_underscore_` (e.g., `gpio_`).
- **Constants**: `kPascalCase` (`kMaxChannels`).
- **Macros**: `ALL_CAPS_WITH_UNDERSCORES` (use sparingly).
- **Aliases**: `using Sample = uint16_t;` (avoid `typedef` in new code).

---

## Language Use
### C++
- **C++17+** (or project default). Prefer `<array>`, `<span>`, `<optional>`, `<chrono>`.
- **No exceptions / no RTTI** by default (size & determinism). Use `Status` returns.
- Prefer **`enum class`**; avoid unscoped enums.
- Prefer **`constexpr`** & **`const`** over macros; **`static`** for internal linkage.
- RAII for HW resources when feasible (GPIO claim/release), but keep ISRs free of heavy constructs.

### C (when used)
- Follow same formatting; `snake_case` for functions/vars is acceptable in pure-C modules.
- Use fixed-width integers from `<stdint.h>`.

---

## 6) APIs & Headers
- Headers are **self-contained** (compile on their own).
- Forward-declare where practical; don’t `#include` what you don’t use.
- Public API gets a brief Doxygen block:
```cpp
/// Samples N channels via a 74HC4051 into the Pico ADC.
/// Blocking; ~200 µs per channel typical.
/// @param channels logical channel indices [0..2]
/// @return last sampled value in 12-bit right-aligned format.
uint16_t SampleOnce(int channel);
```

---

## Error Handling & Logging
- Return `bool` / small `Status` enums for expected errors; no exceptions.
- For fatal HW config errors in bring-up/demo code, `assert()` is acceptable (not in library hot paths).
- Logging:
  - Default to **UART stdio** (`pico_enable_stdio_uart(... 1)`).
  - Use minimal `fprintf(stderr, ...)`/`printf()` in libraries; let programs decide verbosity.

---

## Embedded Rules (Pico/RP2040)
- **ISRs**: `static inline` where sensible; **no malloc/new**, no `printf`, keep <50 µs.
- **Volatile** only for MMIO or truly shared flags; pair with memory barriers when needed.
- **Concurrency**: prefer RP2040 primitives (IRQ disable windows, multicore queues, spinlocks) with brief critical sections.
- **Timing**: use `absolute_time_t` / `busy_wait_us()` from pico-time; avoid ad-hoc loops.
- **GPIO**: configure once in init; document pin ownership in module comments.
- **DMA/PWM/ADC**: place registers/config in one module; avoid cross-module control.

---

## Comments & Documentation
- Prefer short, clear comments explaining *why*, not *what*.
- File header (top 6 lines): one-sentence purpose, dependencies, hardware notes, author/owner.
- Use Doxygen for public APIs; keep private helpers undocumented unless non-obvious.

---

## Sample Skeleton

```cpp
// adc-sampler.h
#pragma once
#include <cstdint>
namespace brain::io {

class AdcSampler {
  public:
    bool init();                   // config ADC + mux GPIOs
    uint16_t sampleChannel(int channel);  // 0..2

  private:
    void selectMux(int channel);
    uint16_t readAdcOnce();

  int adc_channel_ = 0;
};

}  // namespace brain::io
```

```cpp
// adc-sampler.cc
#include "brain-io/adc-sampler.h"
#include "pico/stdlib.h"
#include "hardware/adc.h"

namespace brain::io {

bool AdcSampler::init() {
  adc_init();
  // configure GPIOs, etc.
  return true;
}

uint16_t AdcSampler::sampleChannel(int channel) {
  selectMux(channel);
  sleep_us(10);     // settle
  (void)readAdcOnce(); // throw-away
  return readAdcOnce();
}

void AdcSampler::selectMux(int channel) {
  // drive S0/S1, keep S2 low
}

uint16_t AdcSampler::readAdcOnce() {
  return adc_read();
}

}  // namespace brain::io
```

---

## Things to Avoid
- Global mutable state (except tightly-scoped singletons for HW where necessary).
- Hidden work in constructors; prefer `init()` returning `bool`.
- Long lambdas or templates in embedded hot paths (code size bloat).
- Overuse of macros; prefer `constexpr`, `inline`, and typed enums.

---
---
applyTo: '**/*.h,**/*.cpp,**/*.c'
---
# Project C/C++ Coding Guidelines (Google Style, Embedded-friendly)

> Baseline: Google C++ Style Guide (naming, formatting, includes) with embedded tweaks.

---

Apply the [general coding guidelines](../instructions/general-coding-guidelines.instructions.md) to all code. When found conflicting information, use the instructions in this file.

---

## File Layout & Naming
- **Folders**: use kebab-case → `lib/brain-io/`, `lib/brain-dsp/`.
- **Files**: `lower_case_with_underscores.h` / `.cc` (or `.cpp`).
- **One module per pair**: `brain-io/gpio_driver.h` ↔ `brain-io/gpio_driver.cc`.
- **No mega-files**: prefer small, testable units.

**Header guard** (prefer `#pragma once` for brevity):
```cpp
#pragma once
// or, if guards required:
// #ifndef BRAIN_IO_GPIO_DRIVER_H_
// #define BRAIN_IO_GPIO_DRIVER_H_
// ...
// #endif  // BRAIN_IO_GPIO_DRIVER_H_
```

---

## Includes & Dependencies
Order in both headers and sources:
1. C system headers (`<stdint.h>`, `<stddef.h>`)
2. C++ standard (`<array>`, `<span>`, `<optional>`)
3. Pico/3rd-party (`<pico/stdlib.h>`, `hardware/gpio.h`)
4. Project headers (`"brain-io/gpio_driver.h"`)

One include per line; no wildcard includes. Prefer forward declarations in headers where possible.

---

## Formatting
- **Indent**: 4 spaces; **Line length**: 100.
- **Braces**: K&R style.
```cpp
if (ready) {
    DoThing();
} else {
    HandleError();
}
```
- **Namespace**: wrap entire file; avoid anonymous namespaces in headers.
```cpp
namespace brain::io {
// ...
}  // namespace brain::io
```

---

## Naming
- **Namespaces**: `lower_case` (e.g., `brain::io`).
- **Types / Classes / Structs / Enums**: `PascalCase` (e.g., `AdcSampler`).
- **Functions & Methods**: `camelCase` (e.g., `init()`, `readChannel()`).
- **Variables**: `lower_case_with_underscores` (`sample_rate_hz`).
  - **Data members**: `trailing_underscore_` (e.g., `gpio_`).
- **Constants**: `kPascalCase` (`kMaxChannels`).
- **Macros**: `ALL_CAPS_WITH_UNDERSCORES` (use sparingly).
- **Aliases**: `using Sample = uint16_t;` (avoid `typedef` in new code).

---

## Language Use
### C++
- **C++17+** (or project default). Prefer `<array>`, `<span>`, `<optional>`, `<chrono>`.
- **No exceptions / no RTTI** by default (size & determinism). Use `Status` returns.
- Prefer **`enum class`**; avoid unscoped enums.
- Prefer **`constexpr`** & **`const`** over macros; **`static`** for internal linkage.
- RAII for HW resources when feasible (GPIO claim/release), but keep ISRs free of heavy constructs.

### C (when used)
- Follow same formatting; `snake_case` for functions/vars is acceptable in pure-C modules.
- Use fixed-width integers from `<stdint.h>`.

---

## 6) APIs & Headers
- Headers are **self-contained** (compile on their own).
- Forward-declare where practical; don’t `#include` what you don’t use.
- Public API gets a brief Doxygen block:
```cpp
/*
 * @brief Samples N channels via a 74HC4051 into the Pico ADC.
 *
 * @param channels logical channel indices [0..2]
 * @return last sampled value in 12-bit right-aligned format.
 * /
uint16_t sampleOnce(int channel);
```

---

## Error Handling & Logging
- Return `bool` / small `Status` enums for expected errors; no exceptions.
- For fatal HW config errors in bring-up/demo code, `assert()` is acceptable (not in library hot paths).
- Logging:
  - Default to **UART stdio** (`pico_enable_stdio_uart(... 1)`).
  - Use minimal `fprintf(stderr, ...)`/`printf()` in libraries; let programs decide verbosity.

---

## Embedded Rules (Pico/RP2040)
- **ISRs**: `static inline` where sensible; **no malloc/new**, no `printf`, keep <50 µs.
- **Volatile** only for MMIO or truly shared flags; pair with memory barriers when needed.
- **Concurrency**: prefer RP2040 primitives (IRQ disable windows, multicore queues, spinlocks) with brief critical sections.
- **Timing**: use `absolute_time_t` / `busy_wait_us()` from pico-time; avoid ad-hoc loops.
- **GPIO**: configure once in init; document pin ownership in module comments.
- **DMA/PWM/ADC**: place registers/config in one module; avoid cross-module control.

---

## Comments & Documentation
- Prefer short, clear comments explaining *why*, not *what*.
- File header (top 6 lines): one-sentence purpose, dependencies, hardware notes, author/owner.
- Use Doxygen for public APIs; keep private helpers undocumented unless non-obvious.

---

## Sample Skeleton

```cpp
// adc-sampler.h
#pragma once
#include <cstdint>
namespace brain::io {

class AdcSampler {
  public:
    bool init();                   // config ADC + mux GPIOs
    uint16_t sampleChannel(int channel);  // 0..2

  private:
    void selectMux(int channel);
    uint16_t readAdcOnce();

  int adc_channel_ = 0;
};

}  // namespace brain::io
```

```cpp
// adc-sampler.cc
#include "brain-io/adc-sampler.h"
#include "pico/stdlib.h"
#include "hardware/adc.h"

namespace brain::io {

bool AdcSampler::init() {
  adc_init();
  // configure GPIOs, etc.
  return true;
}

uint16_t AdcSampler::sampleChannel(int channel) {
  selectMux(channel);
  sleep_us(10);     // settle
  (void)readAdcOnce(); // throw-away
  return readAdcOnce();
}

void AdcSampler::selectMux(int channel) {
  // drive S0/S1, keep S2 low
}

uint16_t AdcSampler::readAdcOnce() {
  return adc_read();
}

}  // namespace brain::io
```

---

## Things to Avoid
- Global mutable state (except tightly-scoped singletons for HW where necessary).
- Hidden work in constructors; prefer `init()` returning `bool`.
- Long lambdas or templates in embedded hot paths (code size bloat).
- Overuse of macros; prefer `constexpr`, `inline`, and typed enums.

---

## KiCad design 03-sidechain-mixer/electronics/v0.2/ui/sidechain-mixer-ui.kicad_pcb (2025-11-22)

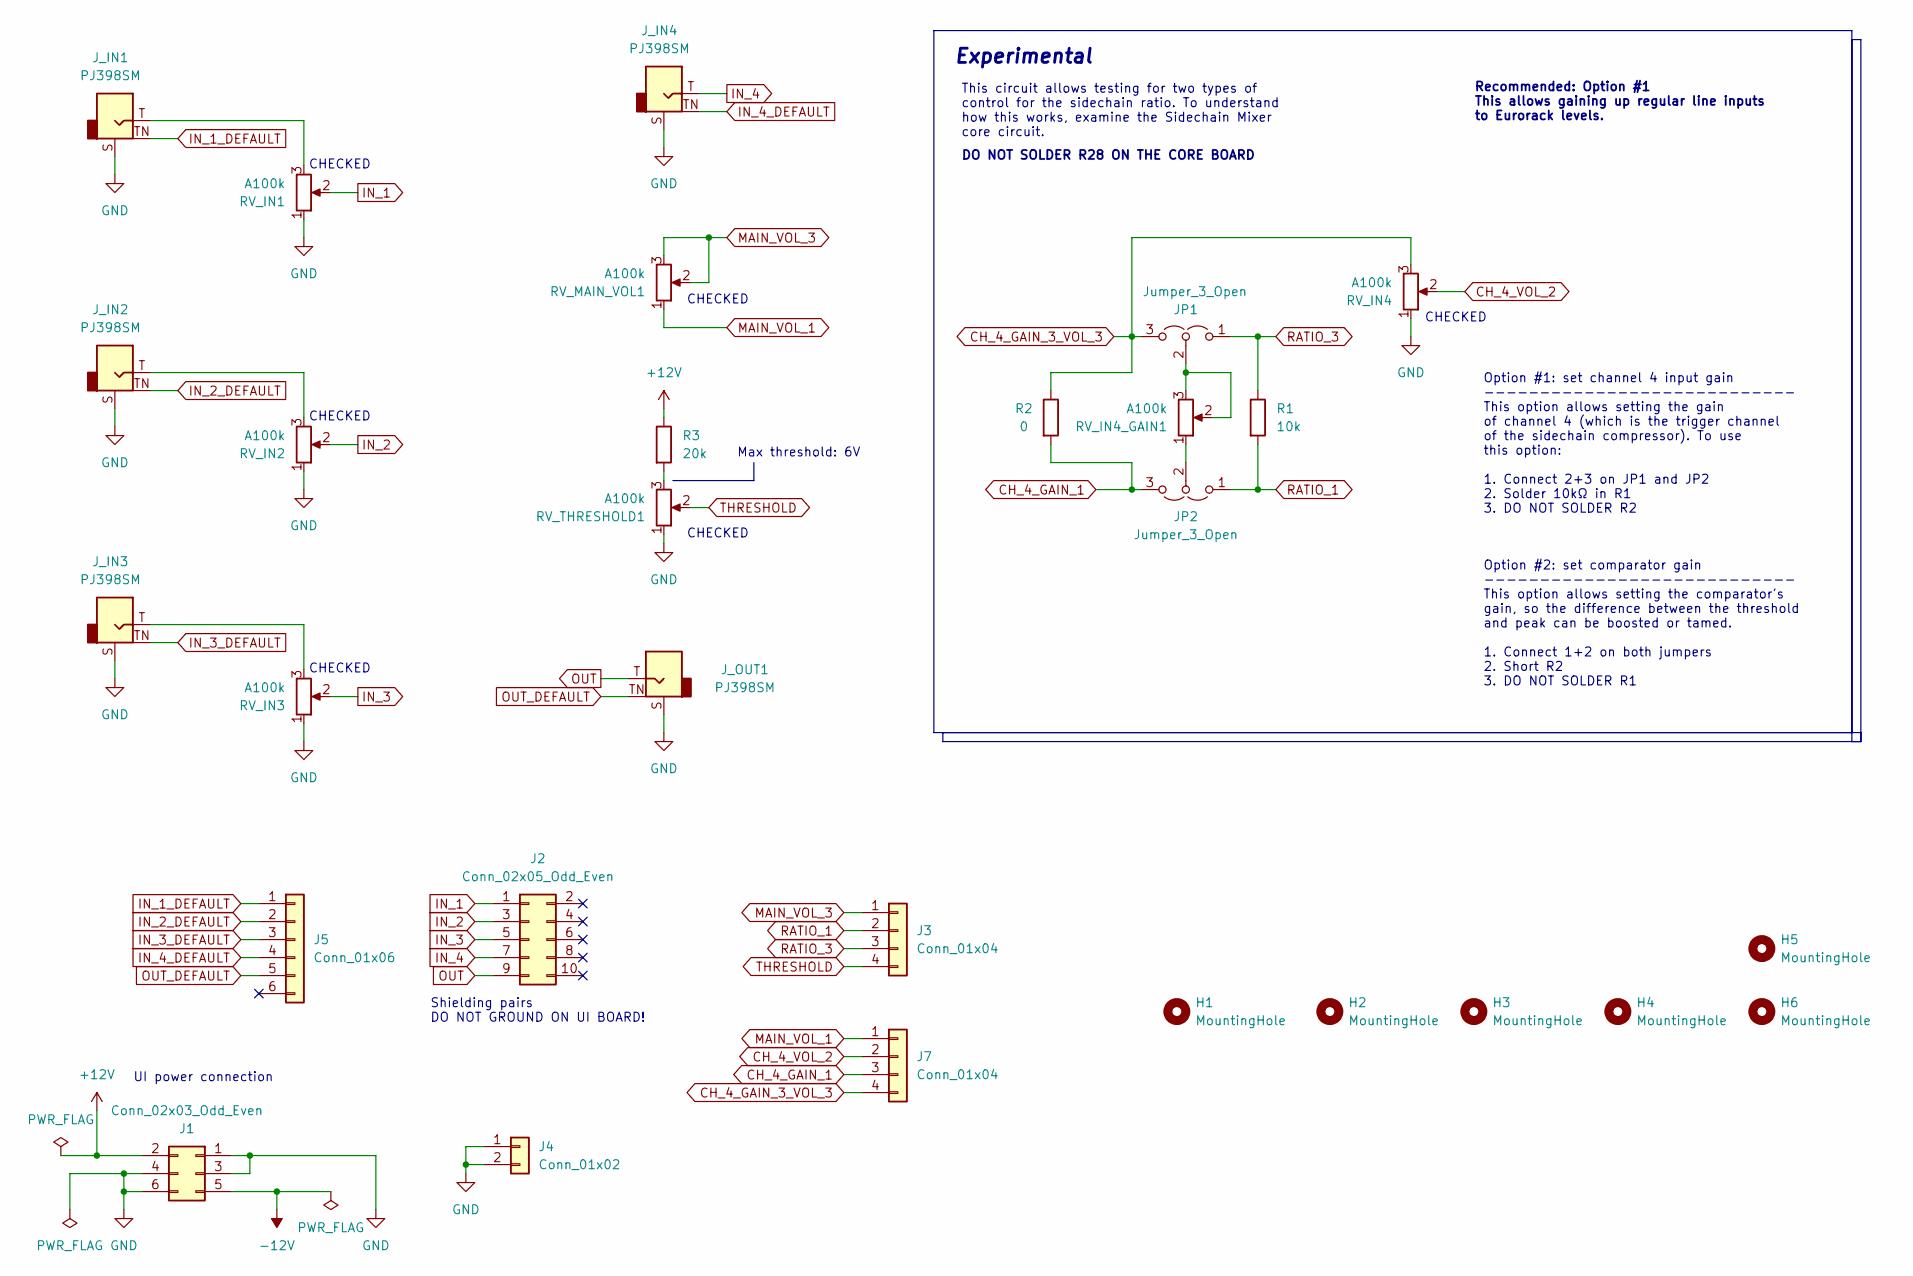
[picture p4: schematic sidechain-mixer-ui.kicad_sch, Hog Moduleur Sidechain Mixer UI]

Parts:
H1, H2, H3, H4, H5, H6: MountingHole; MountingHole_3.2mm_M3_DIN965_Pad
J1: Conn_02x03_Odd_Even; PinSocket_2x03_P2.54mm_Vertical; Part no. 200-SSW10301TD
J2: Conn_02x05_Odd_Even; PinSocket_2x05_P2.54mm_Vertical
J3, J7: Conn_01x04; PinHeader_1x04_P2.54mm_Vertical
J4: Conn_01x02; PinSocket_1x02_P2.54mm_Vertical; Part no. 200-SSW10201TS
J5: Conn_01x06; PinSocket_1x06_P2.54mm_Vertical; Part no. 200-SSW10601TS
JP1, JP2: Jumper_3_Open; PinHeader_1x03_P2.54mm_Vertical
J_IN1, J_IN2, J_IN3, J_IN4: PJ398SM; Jack_3.5mm_QingPu_WQP-PJ398SM_Vertical_CircularHoles; Part no. PJ398SM
J_OUT1: PJ398SM; Jack_3.5mm_QingPu_WQP-PJ398SM_Vertical_CircularHoles; Part no. PJ398SM
R1: 10k; R_Axial_DIN0207_L6.3mm_D2.5mm_P7.62mm_Horizontal
R2: 0; R_Axial_DIN0207_L6.3mm_D2.5mm_P7.62mm_Horizontal
R3: 20k; R_Axial_DIN0207_L6.3mm_D2.5mm_P7.62mm_Horizontal
RV_IN1, RV_IN2, RV_IN3: A100k; TRIM_PTA3043-2010CIA503; Part no. 652-PTA30432015A104
RV_IN4, RV_IN4_GAIN1: A100k; Potentiometer_Bourns_Single-PTV09A; Part no. 652-PTV09A4025FB104
RV_MAIN_VOL1: A100k; Potentiometer_Bourns_Single-PTV09A; Part no. 652-PTV09A4025FB104
RV_THRESHOLD1: A100k; Potentiometer_Bourns_Single-PTV09A; Part no. 652-PTV09A4025FB104

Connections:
+12V: J1.2, R3.1
-12V: J1.5
CH_4_GAIN_1: J7.3, JP2.3 (B), R2.2
CH_4_GAIN_3_VOL_3: J7.4, JP1.3 (B), R2.1, RV_IN4.3
CH_4_VOL_2: J7.2, RV_IN4.2
GND: J1.1, J1.3, J1.4, J1.6, J4.1, J4.2, J_IN1.S, J_IN2.S, J_IN3.S, J_IN4.S, J_OUT1.S, RV_IN1.1, RV_IN2.1, RV_IN3.1, RV_IN4.1, RV_THRESHOLD1.1
IN_1: J2.1, RV_IN1.2
IN_1_DEFAULT: J5.1, J_IN1.TN
IN_2: J2.3, RV_IN2.2
IN_2_DEFAULT: J5.2, J_IN2.TN
IN_3: J2.5, RV_IN3.2
IN_3_DEFAULT: J5.3, J_IN3.TN
IN_4: J2.7, J_IN4.T
IN_4_DEFAULT: J5.4, J_IN4.TN
MAIN_VOL_1: J7.1, RV_MAIN_VOL1.1
MAIN_VOL_3: J3.1, RV_MAIN_VOL1.2, RV_MAIN_VOL1.3
unnamed: JP1.2 (C), RV_IN4_GAIN1.2, RV_IN4_GAIN1.3
unnamed: JP2.2 (C), RV_IN4_GAIN1.1
unnamed: J_IN1.T, RV_IN1.3
unnamed: J_IN2.T, RV_IN2.3
unnamed: J_IN3.T, RV_IN3.3
unnamed: R3.2, RV_THRESHOLD1.3
OUT: J2.9, J_OUT1.T
OUT_DEFAULT: J5.5, J_OUT1.TN
RATIO_1: J3.2, JP2.1 (A), R1.2
RATIO_3: J3.3, JP1.1 (A), R1.1
THRESHOLD: J3.4, RV_THRESHOLD1.2

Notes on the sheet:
Recommended: Option #1 This allows gaining up regular line inputs to Eurorack levels.
Option #2: set comparator gain ---------------------------- This option allows setting the comparator's gain, so the difference between the threshold and peak can be boosted or tamed. 1. Connect 1+2 on both jumpers 2. Short R2 3. DO NOT SOLDER R1
Max threshold: 6V
CHECKED
This circuit allows testing for two types of control for the sidechain ratio. To understand how this works, examine the Sidechain Mixer core circuit.
UI power connection
Option #1: set channel 4 input gain ---------------------------- This option allows setting the gain of channel 4 (which is the trigger channel of the sidechain compressor). To use this option: 1. Connect 2+3 on JP1 and JP2 2. Solder 10kΩ in R1 3. DO NOT SOLDER R2
DO NOT SOLDER R28 ON THE CORE BOARD
Experimental
Shielding pairs DO NOT GROUND ON UI BOARD!

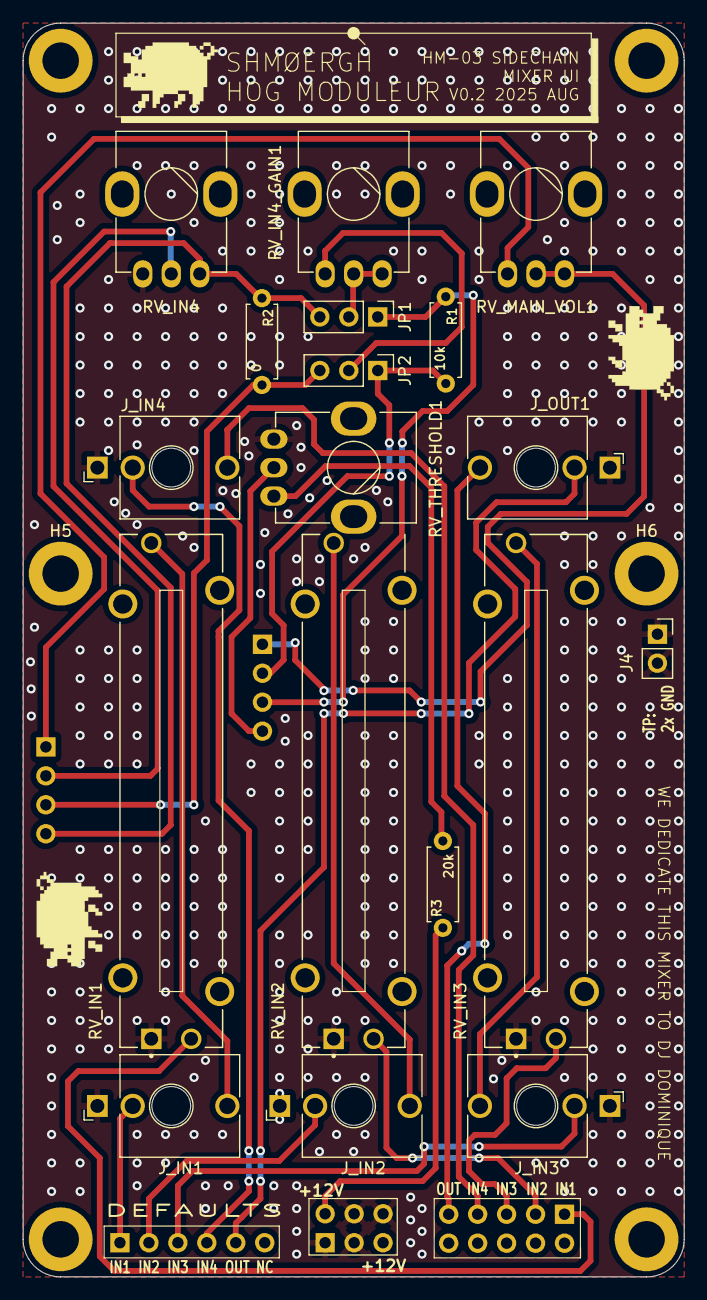
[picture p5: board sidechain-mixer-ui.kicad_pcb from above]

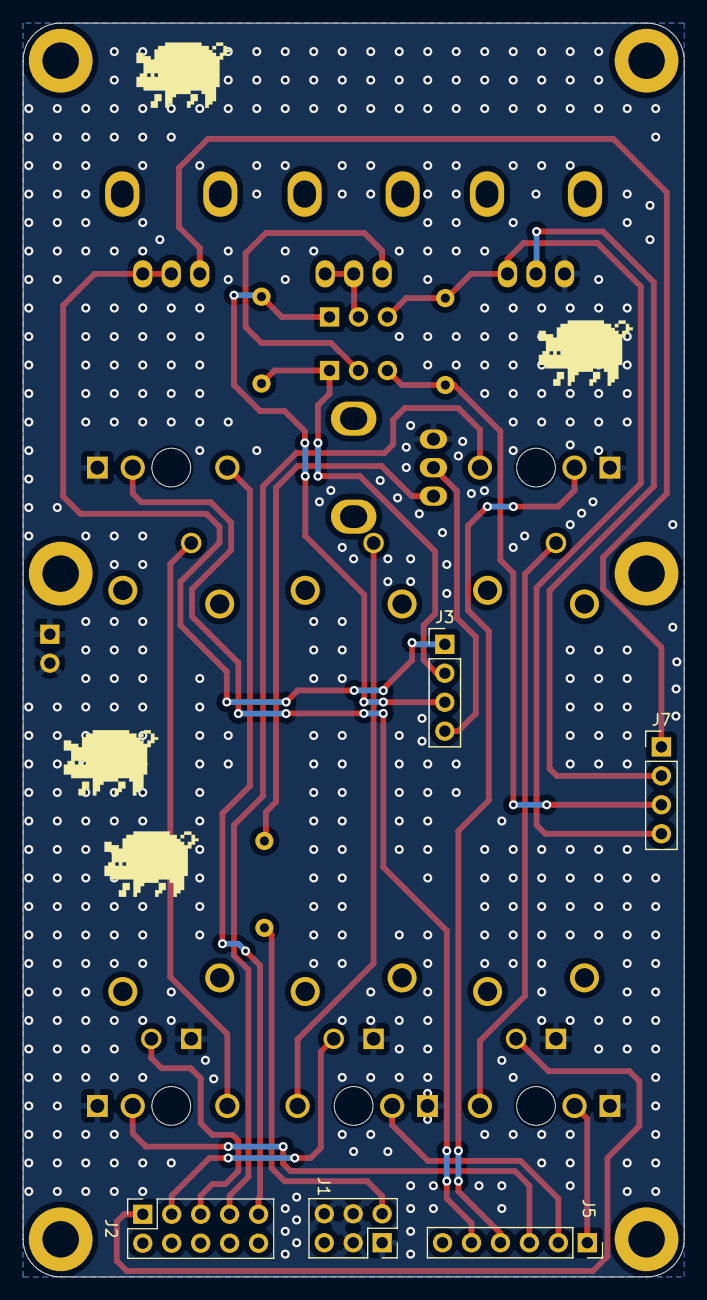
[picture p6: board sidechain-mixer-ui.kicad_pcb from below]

Board: 2 copper layers, 58.0 x 110.0 mm, 29 parts (5 on the bottom side), 26 nets.

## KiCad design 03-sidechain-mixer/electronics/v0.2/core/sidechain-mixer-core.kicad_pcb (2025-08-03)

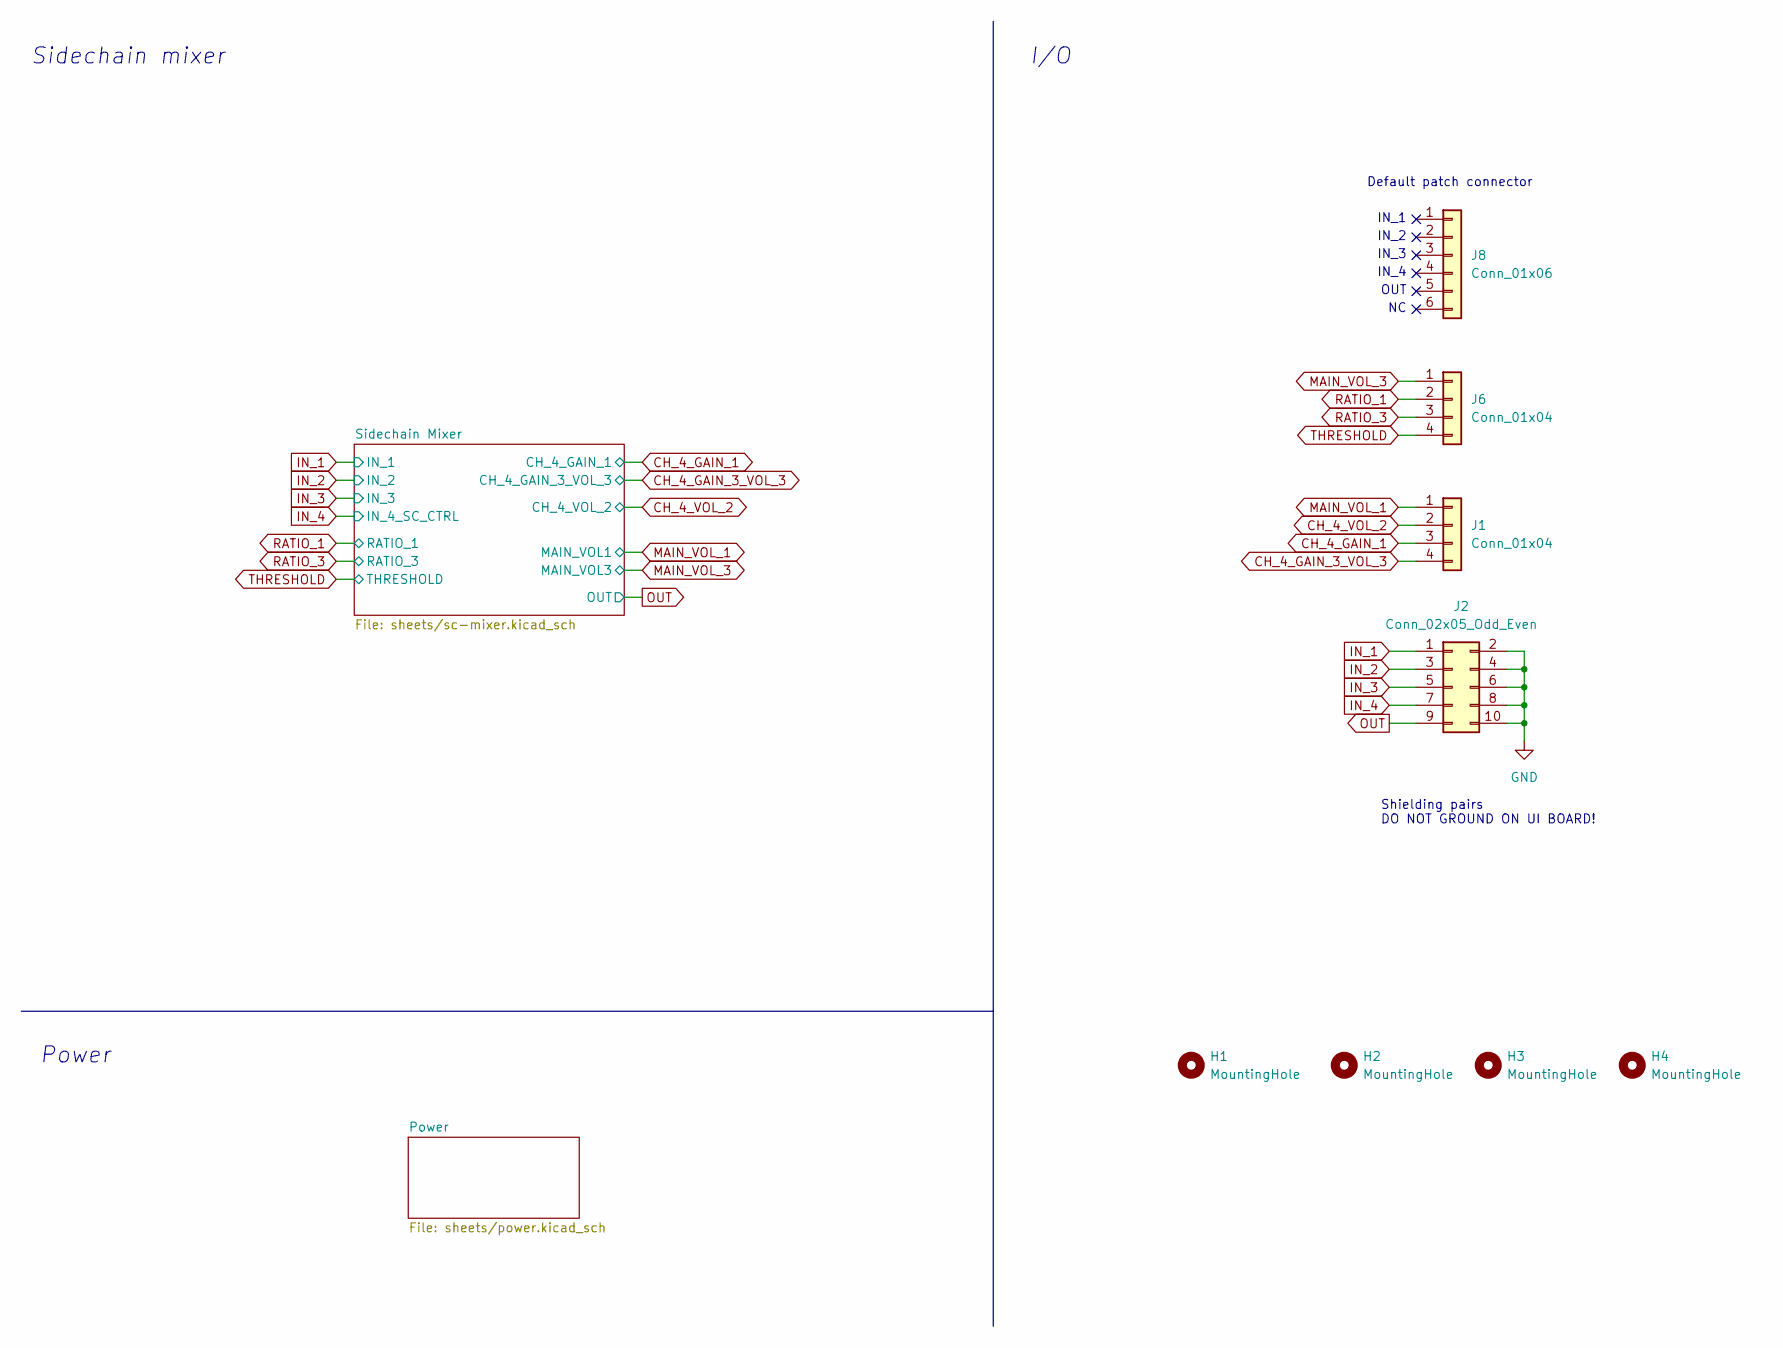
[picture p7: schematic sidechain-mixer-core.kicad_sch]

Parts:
H1, H2, H3, H4: MountingHole; MountingHole_3.2mm_M3_DIN965_Pad
J1, J6: Conn_01x04; PinHeader_1x04_P2.54mm_Vertical
J2: Conn_02x05_Odd_Even; PinHeader_2x05_P2.54mm_Vertical
J8: Conn_01x06; PinHeader_1x06_P2.54mm_Vertical

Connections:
CH_4_GAIN_1: J1.3; also elsewhere on the board
CH_4_GAIN_3_VOL_3: J1.4; also elsewhere on the board
CH_4_VOL_2: J1.2; also elsewhere on the board
IN_1: J2.1; also elsewhere on the board
IN_2: J2.3; also elsewhere on the board
IN_3: J2.5; also elsewhere on the board
IN_4: J2.7; also elsewhere on the board
MAIN_VOL_1: J1.1; also elsewhere on the board
MAIN_VOL_3: J6.1; also elsewhere on the board
OUT: J2.9; also elsewhere on the board
RATIO_1: J6.2; also elsewhere on the board
RATIO_3: J6.3; also elsewhere on the board
THRESHOLD: J6.4; also elsewhere on the board

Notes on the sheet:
Power
IN_3
Default patch connector
IN_1
Shielding pairs DO NOT GROUND ON UI BOARD!
OUT
Sidechain mixer
IN_2
I/O
IN_4

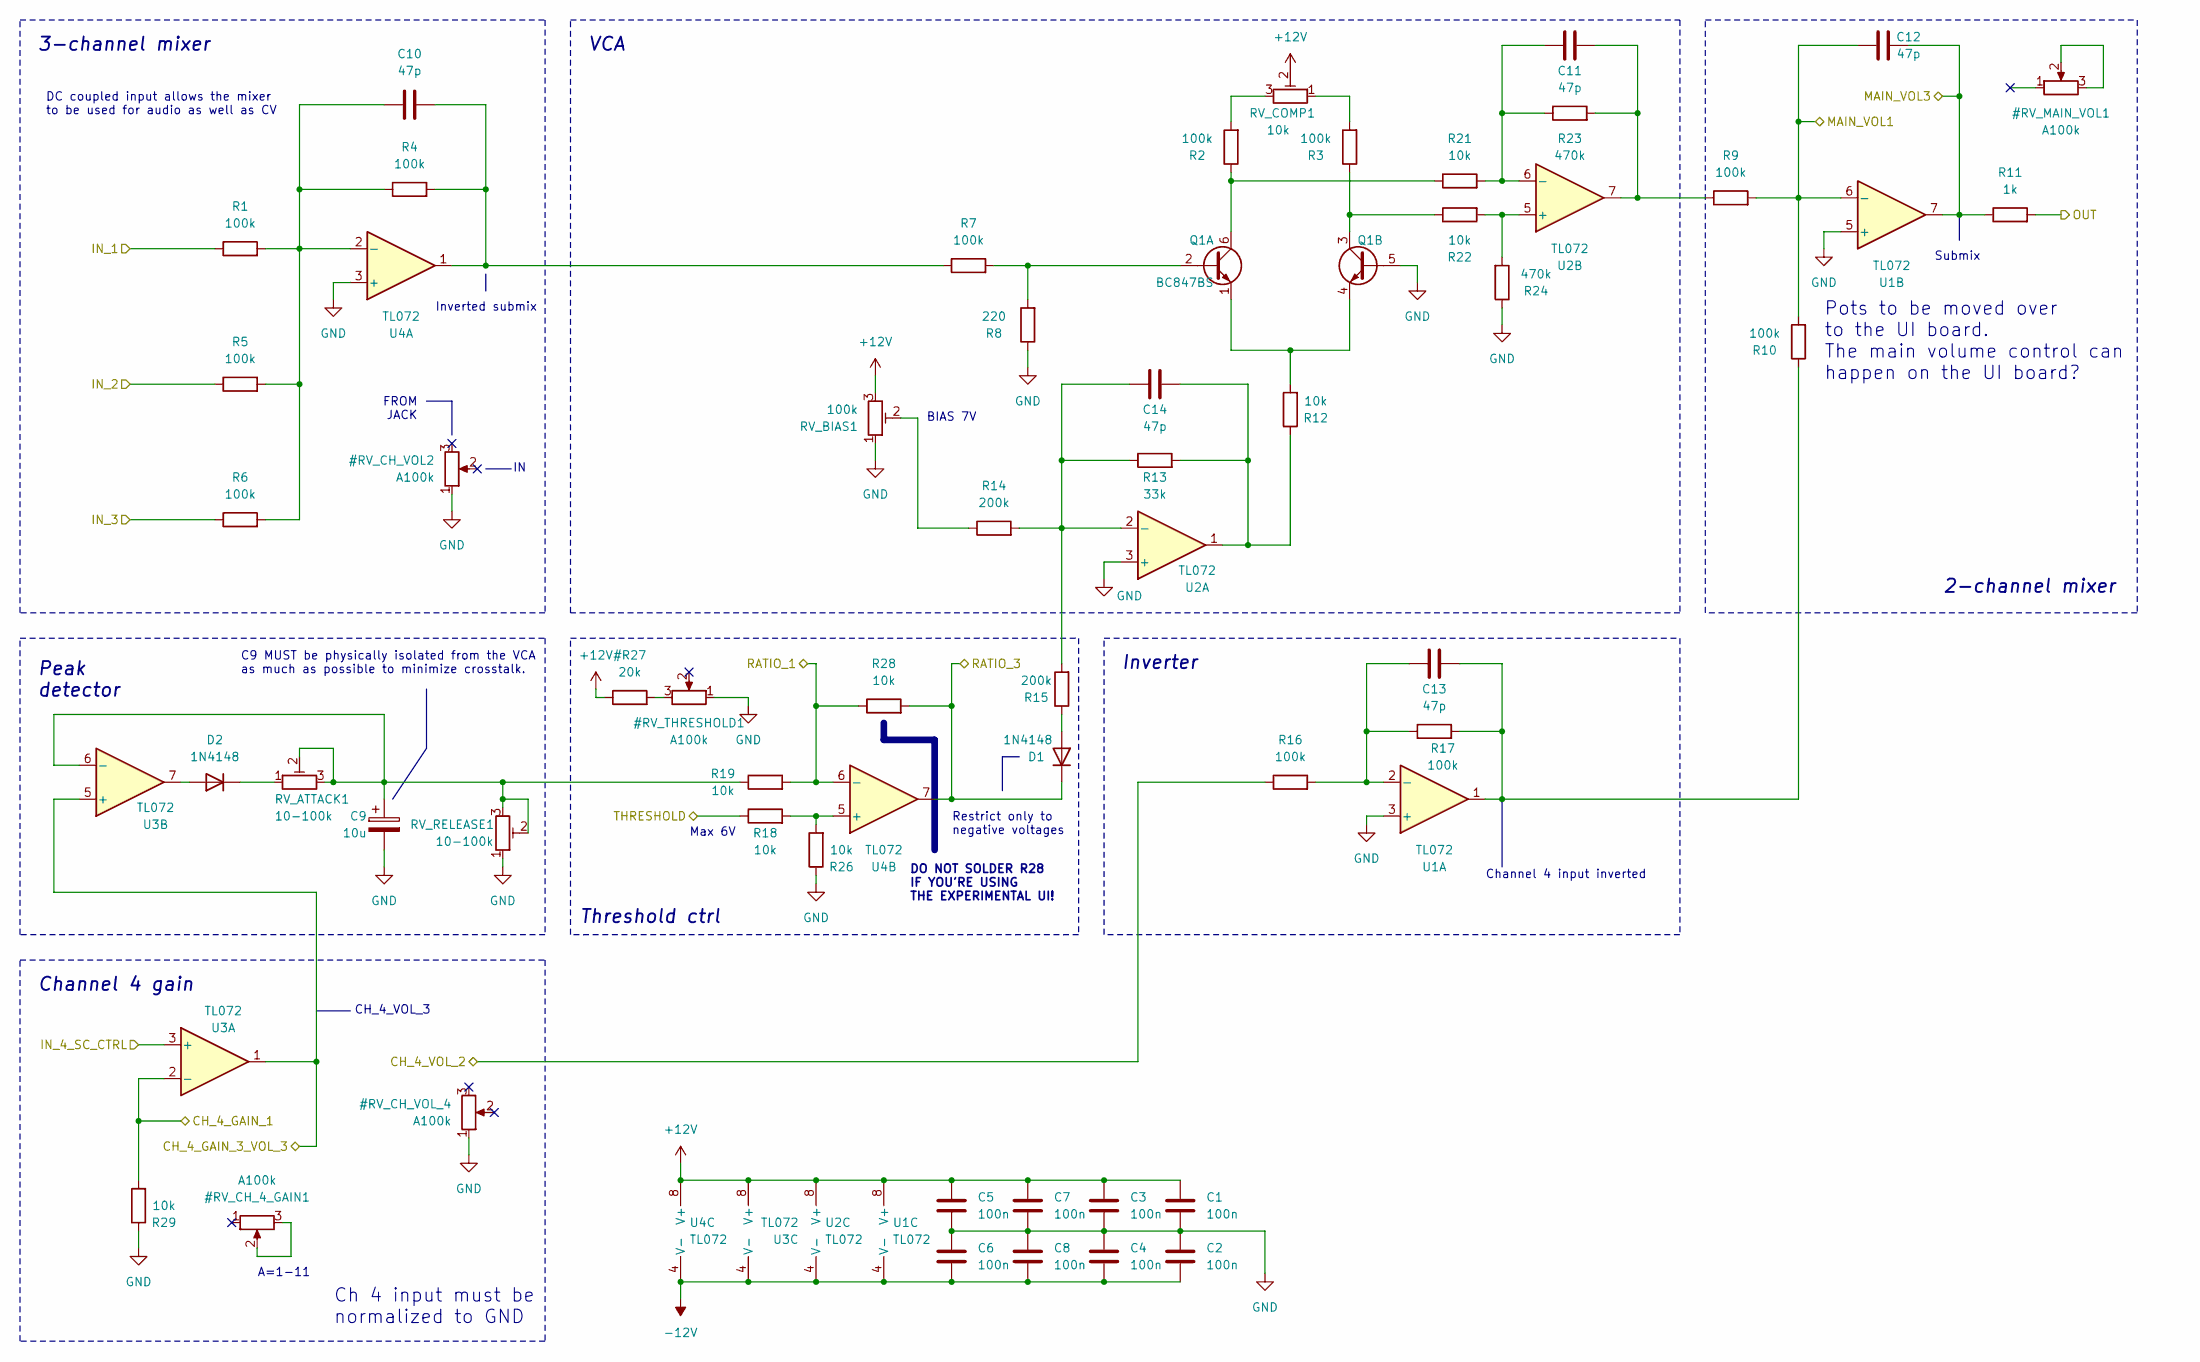
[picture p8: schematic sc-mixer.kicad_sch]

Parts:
C1, C2, C3, C4, C5, C6, C7, C8: 100n; C_0603_1608Metric; LCSC C14663
C9: 10u; CP_Elec_5x5.4; LCSC C30110
C10, C11, C12, C13, C14: 47p; C_0603_1608Metric_Pad1.08x0.95mm_HandSolder; LCSC C1671
D1, D2: 1N4148; D_SOD-123; LCSC C81598
Q1: BC847BS; SOT-363_SC-70-6; LCSC C5380687
R1, R2, R3, R4, R5, R6, R7, R9, R10, R16, R17: 100k; R_0603_1608Metric; LCSC C25803
R8: 220; R_0603_1608Metric; LCSC C22962
R11: 1k; R_0603_1608Metric; LCSC C21190
R12, R21, R22: 10k; R_0603_1608Metric; LCSC C25804
R13: 33k; R_0603_1608Metric; LCSC C4216
R14, R15: 200k; R_0603_1608Metric; LCSC C25811
R18, R19, R26, R28, R29: 10k; R_Axial_DIN0207_L6.3mm_D2.5mm_P7.62mm_Horizontal
R23, R24: 470k; R_0603_1608Metric; LCSC C23178
RV_ATTACK1: 10-100k; Potentiometer_ACP_CA6-H2,5_Horizontal
RV_BIAS1: 100k; Potentiometer_ACP_CA6-H2,5_Horizontal
RV_COMP1: 10k; Potentiometer_ACP_CA6-H2,5_Horizontal
RV_RELEASE1: 10-100k; Potentiometer_ACP_CA6-H2,5_Horizontal
U1, U2, U3, U4: TL072; SOIC-8_3.9x4.9mm_P1.27mm; LCSC C6961

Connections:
-12V: C2.2, C4.2, C6.2, C8.2, U1.4 (V-), U2.4 (V-), U3.4 (V-), U4.4 (V-); also elsewhere on the board
CH_4_GAIN_1: R29.2, U3.2 (-); also elsewhere on the board
CH_4_GAIN_3_VOL_3: U3.1, U3.5 (+); also elsewhere on the board
CH_4_VOL_2: R16.1; also elsewhere on the board
IN_1: R1.1; also elsewhere on the board
IN_2: R5.1; also elsewhere on the board
IN_3: R6.1; also elsewhere on the board
IN_4: U3.3 (+); also elsewhere on the board
MAIN_VOL_1: C12.1, R9.2, R10.2, U1.6 (-); also elsewhere on the board
MAIN_VOL_3: C12.2, R11.1, U1.7; also elsewhere on the board
unnamed: C10.2, R4.2, R7.1, U4.1
unnamed: C11.2, R9.1, R23.2, U2.7
unnamed: C13.2, R10.1, R17.2, U1.1
unnamed: C14.2, R12.1, R13.2, U2.1
unnamed: D1.2 (A), R15.1
unnamed: D2.2 (A), U3.7
unnamed: D2.1 (K), RV_ATTACK1.1
unnamed: Q1.2 (B1), R7.2, R8.2
unnamed: Q1.6 (C1), R2.1, R21.1
unnamed: Q1.1 (E1), Q1.4 (E2), R12.2
unnamed: Q1.3 (C2), R3.1, R22.1
unnamed: R2.2, RV_COMP1.3
unnamed: R3.2, RV_COMP1.1
unnamed: R14.1, RV_BIAS1.2
unnamed: C13.1, R16.2, R17.1, U1.2 (-)
unnamed: C14.1, R13.1, R14.2, R15.2, U2.2 (-)
unnamed: R22.2, R24.2, U2.5 (+)
unnamed: C11.1, R21.2, R23.1, U2.6 (-)
unnamed: C9.1, R19.1, RV_ATTACK1.2, RV_ATTACK1.3, RV_RELEASE1.2, RV_RELEASE1.3, U3.6 (-)
unnamed: C10.1, R1.2, R4.1, R5.2, R6.2, U4.2 (-)
unnamed: R18.2, R26.2, U4.5 (+)
OUT: R11.2; also elsewhere on the board
RATIO_1: R19.2, R28.1, U4.6 (-); also elsewhere on the board
RATIO_3: D1.1 (K), R28.2, U4.7; also elsewhere on the board
THRESHOLD: R18.1; also elsewhere on the board

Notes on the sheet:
2-channel mixer
Channel 4 gain
FROM JACK
A=1-11
Pots to be moved over to the UI board. The main volume control can happen on the UI board?
DO NOT SOLDER R28 IF YOU'RE USING THE EXPERIMENTAL UI!
Inverter
Submix
VCA
BIAS 7V
Channel 4 input inverted
Max 6V
Ch 4 input must be normalized to GND
3-channel mixer
Restrict only to negative voltages
DC coupled input allows the mixer to be used for audio as well as CV
C9 MUST be physically isolated from the VCA as much as possible to minimize crosstalk.
CH_4_VOL_3
Peak detector
Threshold ctrl
Inverted submix

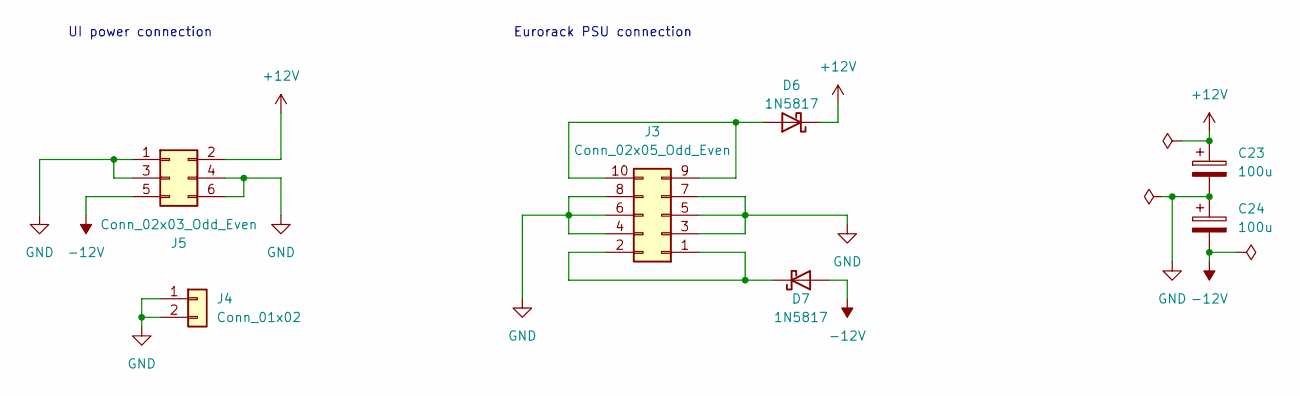
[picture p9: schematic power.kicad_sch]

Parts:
C23, C24: 100u; CP_Elec_6.3x7.7; LCSC C2836437
D6, D7: 1N5817; D_SOD-323; LCSC C5190152
J3: Conn_02x05_Odd_Even; IDC-Header_2x05_P2.54mm_Horizontal
J4: Conn_01x02; PinHeader_1x02_P2.54mm_Vertical
J5: Conn_02x03_Odd_Even; PinHeader_2x03_P2.54mm_Vertical

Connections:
-12V: C24.2, D7.2 (A), J5.5; also elsewhere on the board
unnamed: D6.2 (A), J3.9, J3.10
unnamed: D7.1 (K), J3.1, J3.2

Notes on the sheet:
UI power connection
Eurorack PSU connection

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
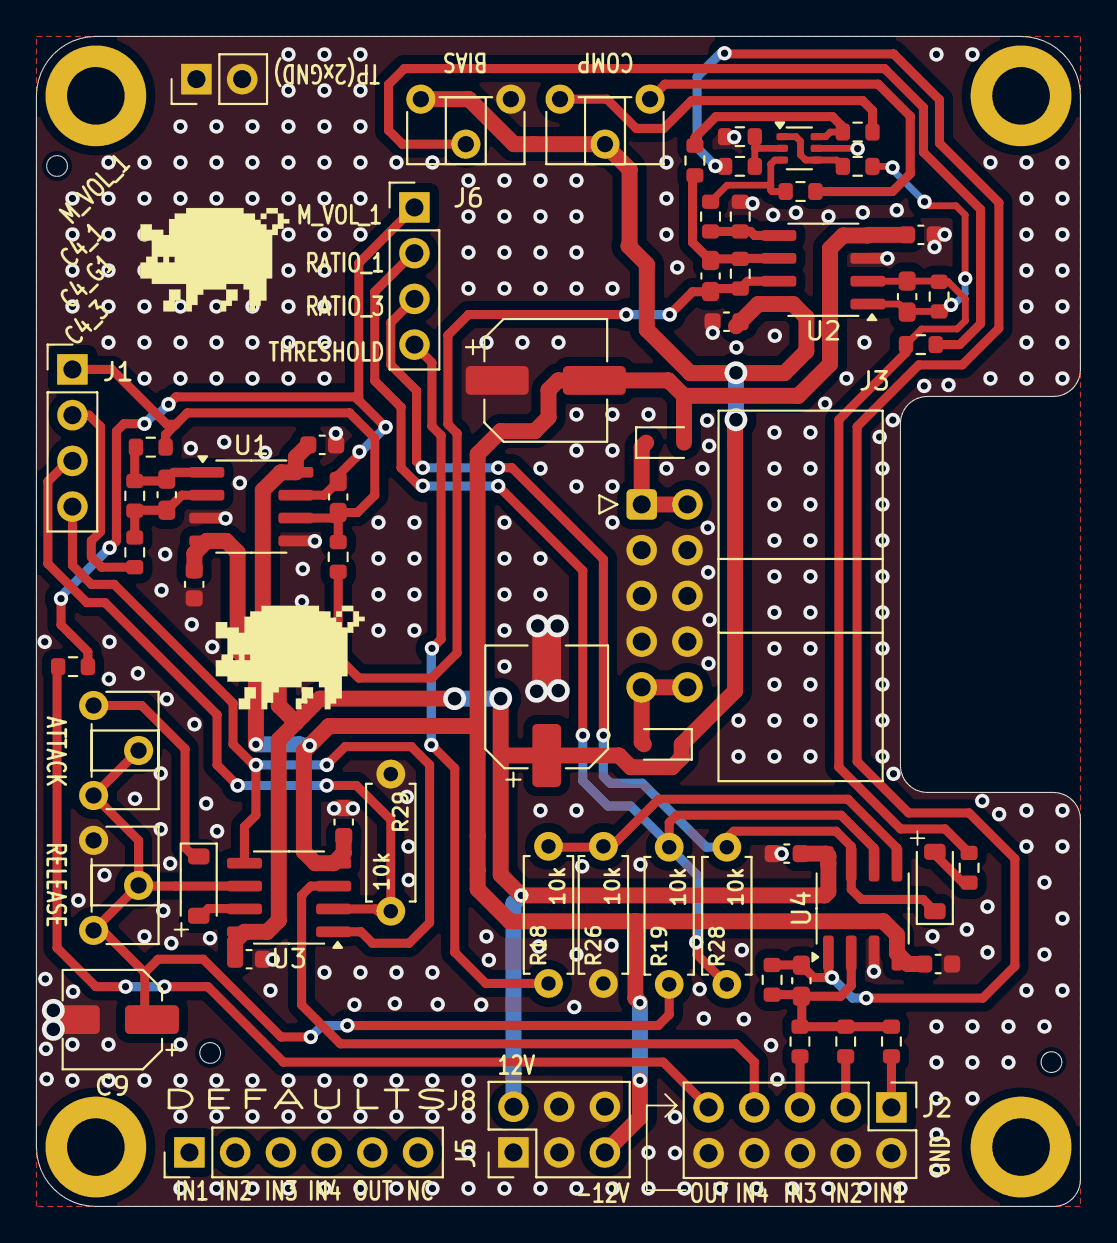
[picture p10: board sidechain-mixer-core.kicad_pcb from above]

Board: 2 copper layers, 58.0 x 65.0 mm, 66 parts (0 on the bottom side), 39 nets.

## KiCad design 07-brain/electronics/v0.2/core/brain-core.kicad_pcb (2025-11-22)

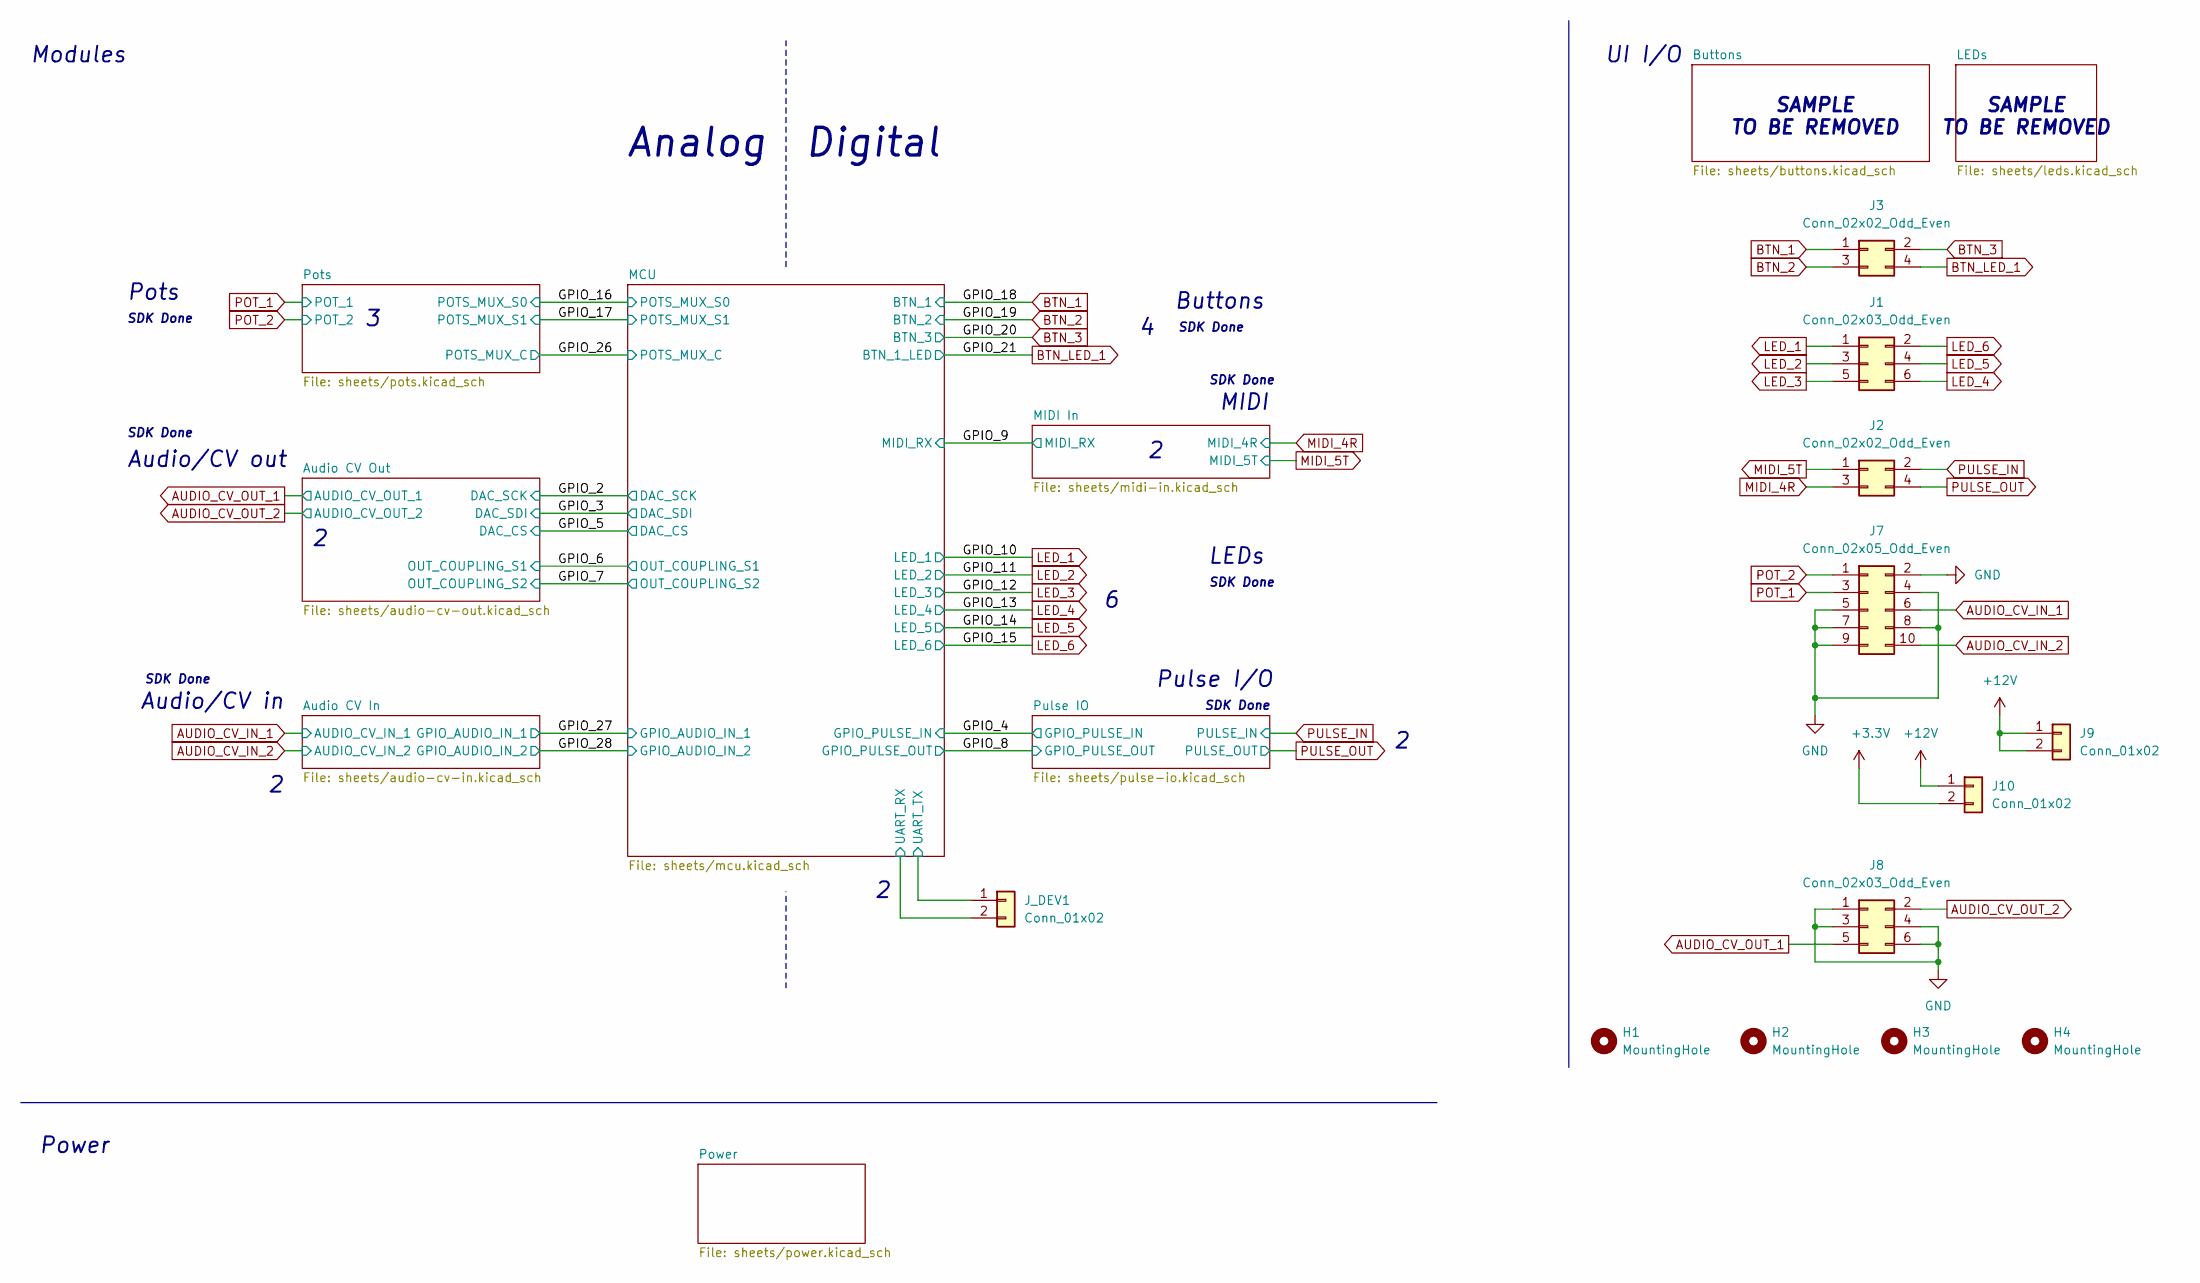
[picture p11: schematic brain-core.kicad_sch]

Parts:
H1, H2, H3, H4: MountingHole; MountingHole_3.2mm_M3_DIN965_Pad
J1, J8: Conn_02x03_Odd_Even; PinHeader_2x03_P2.54mm_Vertical
J2, J3: Conn_02x02_Odd_Even; PinHeader_2x02_P2.54mm_Vertical
J7: Conn_02x05_Odd_Even; PinHeader_2x05_P2.54mm_Vertical
J9, J10: Conn_01x02; PinHeader_1x02_P2.54mm_Vertical
J_DEV1: Conn_01x02; PinHeader_1x02_P2.54mm_Vertical

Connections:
+12V: J9.1, J9.2, J10.1; also elsewhere on the board
/MCU/UART_RX: J_DEV1.2; also elsewhere on the board
/MCU/UART_TX: J_DEV1.1; also elsewhere on the board
AUDIO_CV_IN_1: J7.6; also elsewhere on the board
AUDIO_CV_IN_2: J7.10; also elsewhere on the board
AUDIO_CV_OUT_1: J8.5; also elsewhere on the board
AUDIO_CV_OUT_2: J8.2; also elsewhere on the board
BTN_1: J3.1; also elsewhere on the board
BTN_2: J3.3; also elsewhere on the board
BTN_3: J3.2; also elsewhere on the board
BTN_LED_1: J3.4; also elsewhere on the board
LED_1: J1.1; also elsewhere on the board
LED_2: J1.3; also elsewhere on the board
LED_3: J1.5; also elsewhere on the board
LED_4: J1.6; also elsewhere on the board
LED_5: J1.4; also elsewhere on the board
LED_6: J1.2; also elsewhere on the board
POT_1: J7.3; also elsewhere on the board
POT_2: J7.1; also elsewhere on the board
PULSE_IN: J2.2; also elsewhere on the board
PULSE_OUT: J2.4; also elsewhere on the board

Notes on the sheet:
Power
Audio/CV in
SAMPLE TO BE REMOVED
Pulse I/O
Audio/CV out
SDK Done
LEDs
Modules
Buttons
Analog
Pots
Digital
MIDI
UI I/O

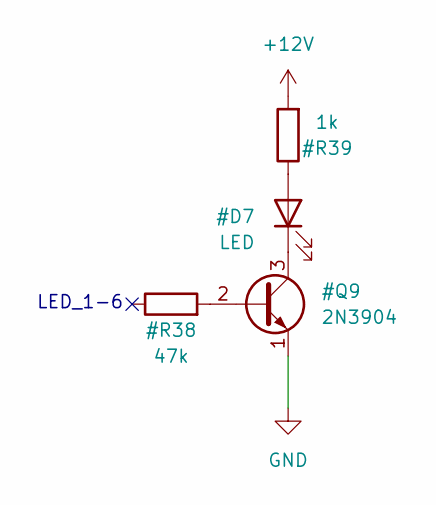
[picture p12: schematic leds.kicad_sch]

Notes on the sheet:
LED_1-6

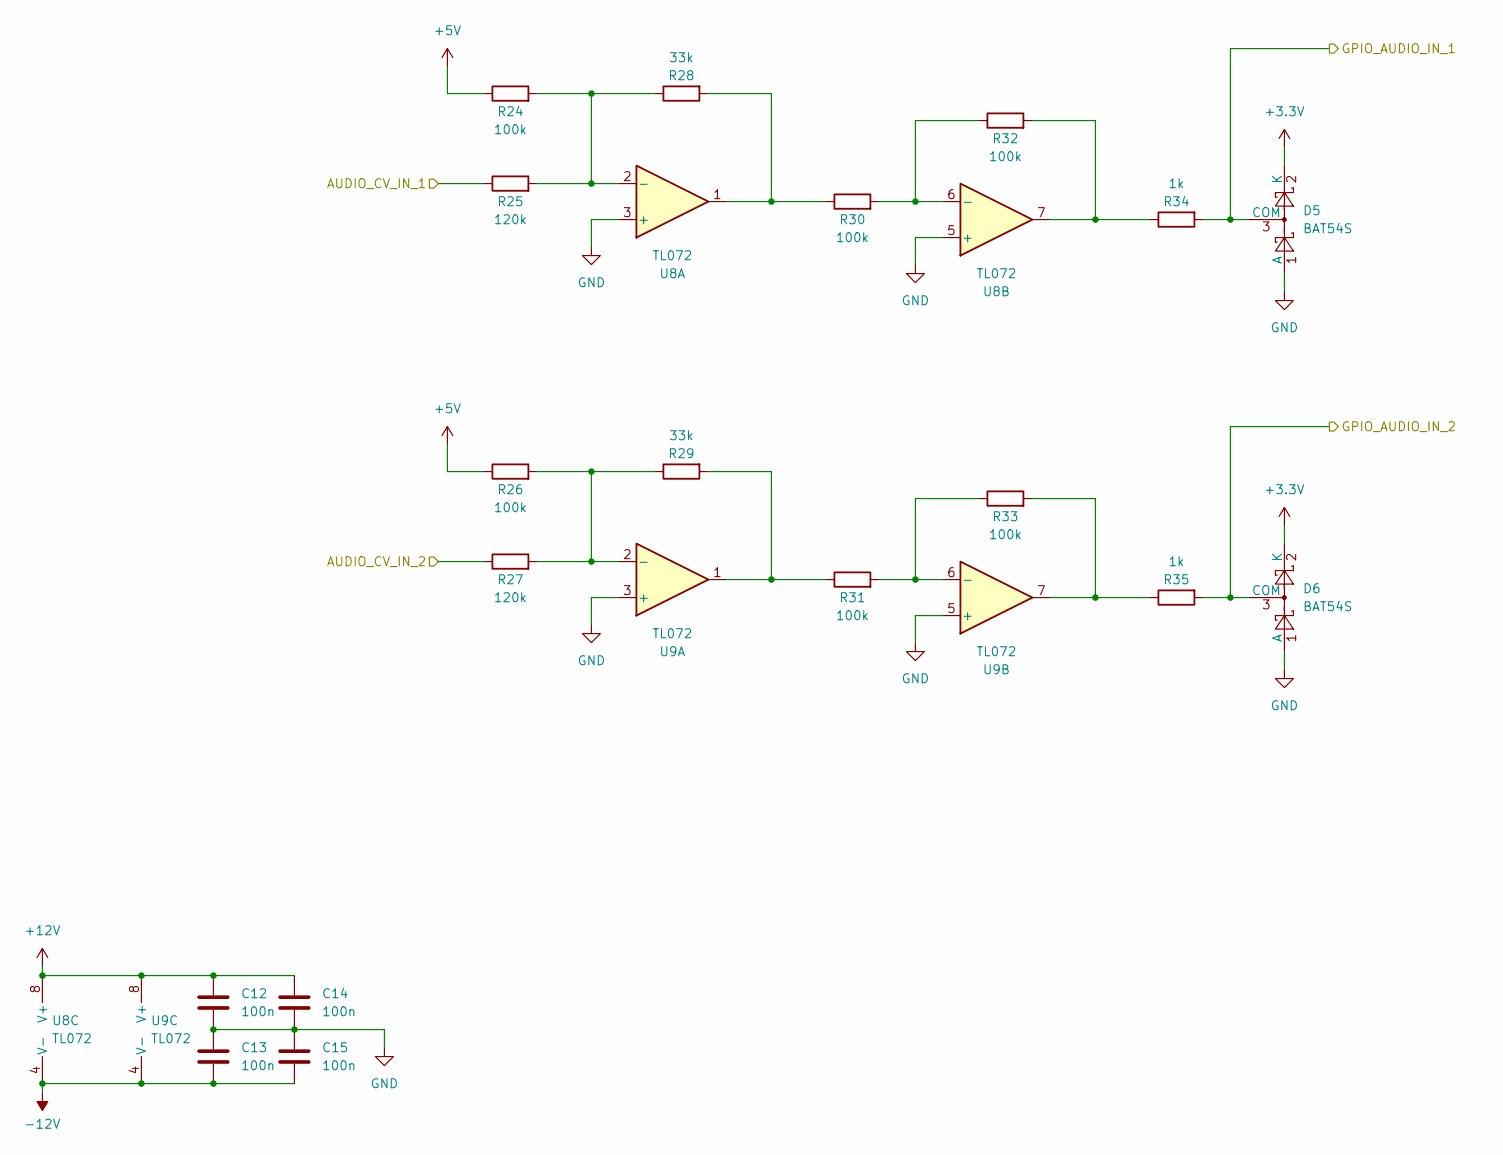
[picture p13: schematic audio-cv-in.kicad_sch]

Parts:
C12, C13, C14, C15: 100n; C_0603_1608Metric; LCSC C14663
D5, D6: BAT54S; SOT-23; LCSC C7420333
R24, R26, R30, R31, R32, R33: 100k; R_0603_1608Metric; LCSC C25803
R25, R27: 120k; R_0603_1608Metric; LCSC C25808
R28, R29: 33k; R_0603_1608Metric; LCSC C4216
R34, R35: 1k; R_0603_1608Metric; LCSC C21190
U8, U9: TL072; SOIC-8_3.9x4.9mm_P1.27mm; LCSC C6961

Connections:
+5V: R24.1, R26.1; also elsewhere on the board
+12V: C12.1, C14.1, U8.8 (V+), U9.8 (V+); also elsewhere on the board
-12V: C13.2, C15.2, U8.4 (V-), U9.4 (V-); also elsewhere on the board
/GPIO_27: D5.3 (COM), R34.2; also elsewhere on the board
/GPIO_28: D6.3 (COM), R35.2; also elsewhere on the board
AUDIO_CV_IN_1: R25.1; also elsewhere on the board
AUDIO_CV_IN_2: R27.1; also elsewhere on the board
unnamed: R28.2, R30.1, U8.1
unnamed: R29.2, R31.1, U9.1
unnamed: R32.2, R34.1, U8.7
unnamed: R33.2, R35.1, U9.7
unnamed: R24.2, R25.2, R28.1, U8.2 (-)
unnamed: R30.2, R32.1, U8.6 (-)
unnamed: R26.2, R27.2, R29.1, U9.2 (-)
unnamed: R31.2, R33.1, U9.6 (-)

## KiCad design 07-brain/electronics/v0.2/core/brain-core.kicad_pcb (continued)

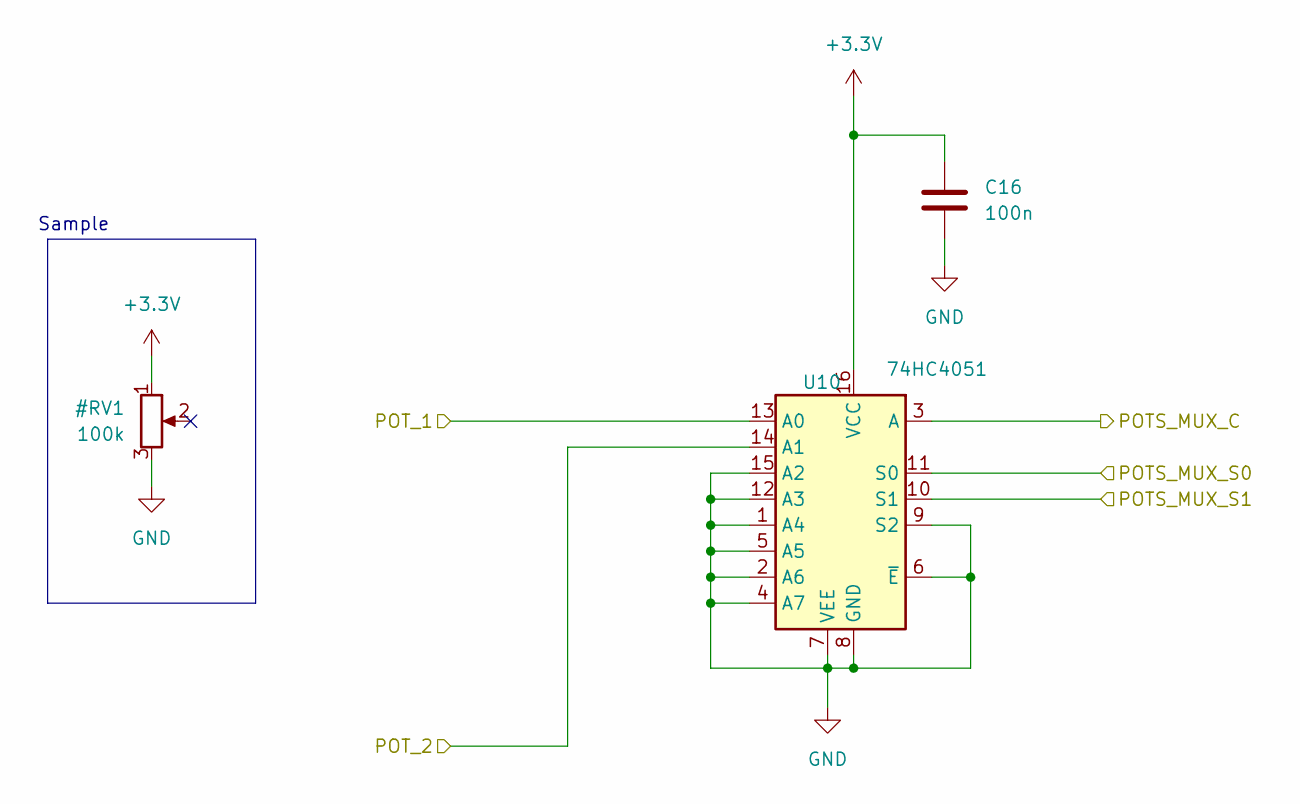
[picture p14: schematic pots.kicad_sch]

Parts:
C16: 100n; C_0603_1608Metric; LCSC C14663
U10: 74HC4051; SOIC-16_3.9x9.9mm_P1.27mm; LCSC C9386

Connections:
/GPIO_16: U10.11 (S0); also elsewhere on the board
/GPIO_17: U10.10 (S1); also elsewhere on the board
/GPIO_26: U10.3 (A); also elsewhere on the board
POT_1: U10.13 (A0); also elsewhere on the board
POT_2: U10.14 (A1); also elsewhere on the board

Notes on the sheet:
Sample

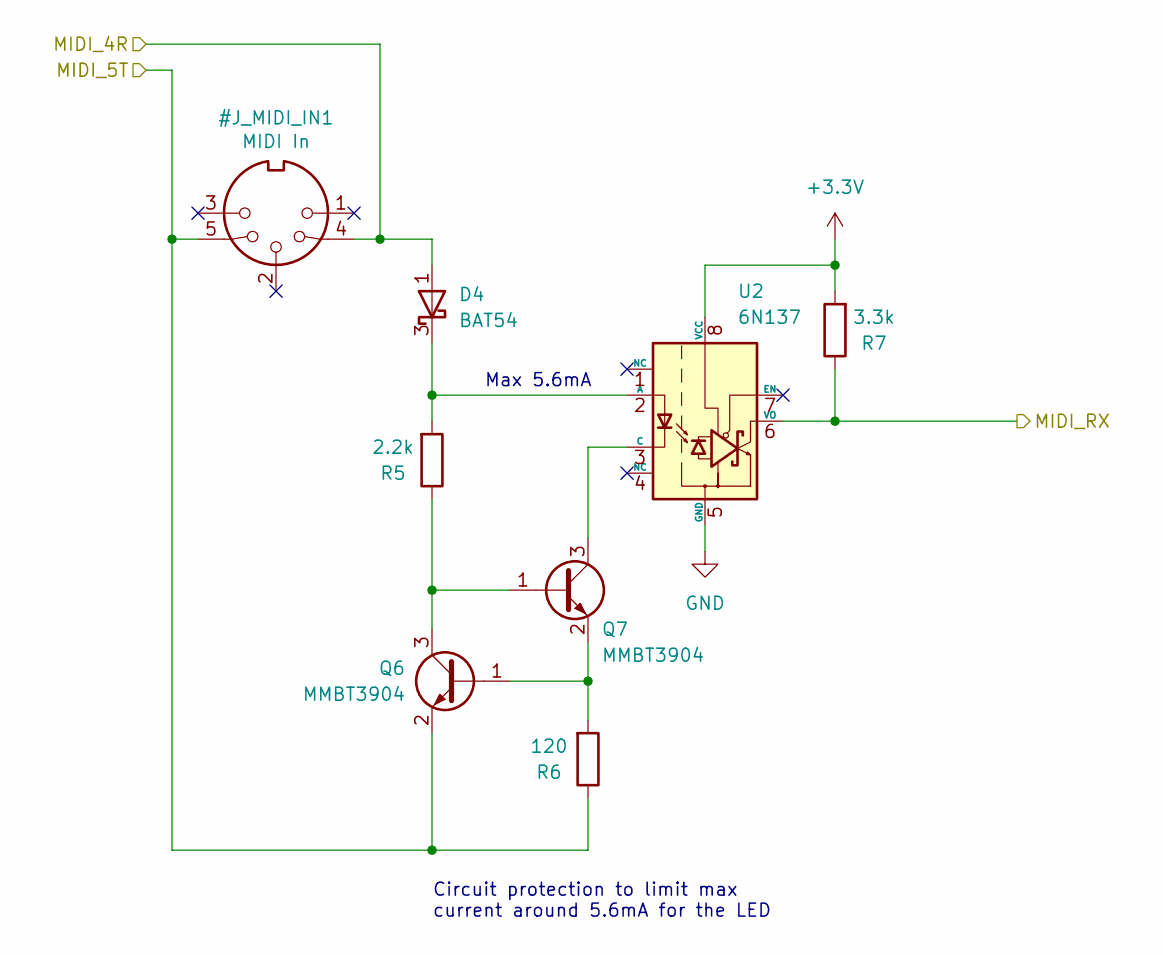
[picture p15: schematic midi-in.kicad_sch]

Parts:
D4: BAT54; SOT-23; LCSC C22466368
Q6, Q7: MMBT3904; SOT-23; LCSC C20526
R5: 2.2k; R_0603_1608Metric; LCSC C4190
R6: 120; R_0603_1608Metric; LCSC C22787
R7: 3.3k; R_0603_1608Metric; LCSC C22978
U2: 6N137; SOP-8_6.605x9.655mm_P2.54mm; LCSC C92651

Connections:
/GPIO_9: R7.1, U2.6 (VO); also elsewhere on the board
unnamed: D4.3 (K), R5.2, U2.2 (A)
unnamed: Q6.1 (B), Q7.2 (E), R6.2
unnamed: Q6.3 (C), Q7.1 (B), R5.1
unnamed: Q7.3 (C), U2.3 (C)

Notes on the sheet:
Max 5.6mA
Circuit protection to limit max current around 5.6mA for the LED


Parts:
C1: 10u; CP_Elec_4x5.4; LCSC C46550410
C2: 330n; C_0603_1608Metric_Pad1.08x0.95mm_HandSolder; LCSC C188679
C3: 100n; C_0603_1608Metric; LCSC C14663
C4, C5: 100u; CP_Elec_6.3x7.7; LCSC C2836437
D1, D2, D3: 1N5817; D_SOD-323; LCSC C5190152
J4: Conn_02x03_Odd_Even; PinHeader_2x03_P2.54mm_Vertical
J5: Conn_01x02; PinHeader_1x02_P2.54mm_Vertical
J6: Conn_02x05_Odd_Even; IDC-Header_2x05_P2.54mm_Horizontal
U1: LM7805_TO220; TO-220-3_Horizontal_TabDown; Part No. 926-LM7805CT/NOPB

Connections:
+5V: D1.1 (K); also elsewhere on the board
+12V: C1.1, C2.1, C4.1, D2.1 (K), J4.2, U1.1 (VI); also elsewhere on the board
-12V: C5.2, D3.2 (A), J4.5; also elsewhere on the board
unnamed: C3.1, D1.2 (A), U1.3 (VO)
unnamed: D2.2 (A), J6.9, J6.10
unnamed: D3.1 (K), J6.1, J6.2

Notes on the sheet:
UI power connection
When flashing programs to MCU, this jumper MUST BE disconnected. The MCU should receive its power from the SWD device (another RPi Pico, Picoprobe).
Eurorack PSU connection


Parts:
C6, C7, C8, C9, C17, C19, C20: 100n; C_0603_1608Metric; LCSC C14663
C10, C11: 22p; C_0603_1608Metric; LCSC C1653
C18: 10u; C_0603_1608Metric; LCSC C19702
R8, R9: 47k; R_0603_1608Metric; LCSC C25819
R10, R11: 62k; R_0603_1608Metric; LCSC C23221
R12, R22, R23: 1k; R_0603_1608Metric; LCSC C21190
R14, R15, R16, R17, R18, R19, R20, R21: 100k; R_0603_1608Metric; LCSC C25803
RV_CV_GAIN1, RV_CV_GAIN2: 10k; Potentiometer_ACP_CA6-H2,5_Horizontal; Part No. 531-PT6KH-10K
U4, U5, U11: TL072; SOIC-8_3.9x4.9mm_P1.27mm; LCSC C6961
U6: MCP4822; SOIC-8_3.9x4.9mm_P1.27mm; LCSC C623653
U7: 74HC4053B; SOIC-16_3.9x9.9mm_P1.27mm; LCSC C5647

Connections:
+5V: C17.1, C18.1, U6.1 (Vdd), U7.1 (B1), U7.13 (A1), U7.16 (VDD); also elsewhere on the board
+12V: C6.1, C8.1, C19.1, U4.8 (V+), U5.8 (V+), U11.8 (V+); also elsewhere on the board
-12V: C7.2, C9.2, C20.2, U4.4 (V-), U5.4 (V-), U11.4 (V-); also elsewhere on the board
/GPIO_2: U6.3 (SCK); also elsewhere on the board
/GPIO_3: U6.4 (SDI); also elsewhere on the board
/GPIO_5: U6.2 (~CS); also elsewhere on the board
/GPIO_6: U7.11 (S1); also elsewhere on the board
/GPIO_7: U7.10 (S2); also elsewhere on the board
AUDIO_CV_OUT_1: R23.2, U11.6 (-); also elsewhere on the board
AUDIO_CV_OUT_2: R22.2, U11.2 (-); also elsewhere on the board
unnamed: C10.2, R12.1, U4.1
unnamed: C11.2, R15.1, RV_CV_GAIN1.2, RV_CV_GAIN1.3, U5.1
unnamed: R10.2, RV_CV_GAIN2.1
unnamed: R11.2, RV_CV_GAIN1.1
unnamed: R12.2, R14.1, RV_CV_GAIN2.2, RV_CV_GAIN2.3
unnamed: R22.1, U11.1
unnamed: R23.1, U11.7
unnamed: U4.3 (+), U6.6 (VB)
unnamed: C10.1, R8.2, R10.1, U4.2 (-)
unnamed: R14.2, R16.2, U4.5 (+)
unnamed: R19.1, R20.1, U4.6 (-)
unnamed: U5.3 (+), U6.8 (VA)
unnamed: C11.1, R9.2, R11.1, U5.2 (-)
unnamed: R15.2, R17.2, U5.5 (+)
unnamed: R18.2, R21.1, U5.6 (-)
unnamed: R18.1, U7.14 (A)
unnamed: R19.2, U7.15 (B)
unnamed: R20.2, U4.7, U11.3 (+)
unnamed: R21.2, U5.7, U11.5 (+)

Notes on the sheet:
Simulated DC/AC coupling controlled by the Pico.
Subtractor circuit: when OUT_COUPLING_S1 is high it shifts the output by -5V, simulating AC coupling. DC coupling output (OUT_COUPLING_S1 = 0): 0-10V Simulated AC coupling output (OUT_COUPLING_S1 = 1): -5V - 5V
Tune: Set DAC to max (4095mV) Output should be 10V
Non-inverting amplifier converting 4095mV to approximately 10V. DAC out: 0-4095mV Output: 0-10V


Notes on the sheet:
BTN_LED_1
BTN_LED_2
BTN_2
BTN_1

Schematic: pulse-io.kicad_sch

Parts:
Q1, Q3: MMBT3904; SOT-23; LCSC C20526
R1: 100k; R_0603_1608Metric; LCSC C25803
R2: 3.3k; R_0603_1608Metric; LCSC C22978
R3: 10k; R_0603_1608Metric; LCSC C25804
R4: 7.5k; R_0603_1608Metric; LCSC C23234

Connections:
+12V: R3.2; also elsewhere on the board
/GPIO_4: Q1.3 (C); also elsewhere on the board
/GPIO_8: R2.1; also elsewhere on the board
unnamed: Q1.1 (B), R1.2
unnamed: Q3.1 (B), R2.2
PULSE_IN: R1.1; also elsewhere on the board
PULSE_OUT: Q3.3 (C), R3.1, R4.2; also elsewhere on the board

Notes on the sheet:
About 5.1V pulses
Use Pico's pull up resistor to set value to logical 1. On pulse in, it goes to 0.
Pulse is inverted. Since the input is inverted too, if you just want to let pulses through you don't need to invert anything.

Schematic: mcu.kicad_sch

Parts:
J11: Conn_01x01; PinHeader_1x01_P2.54mm_Vertical
J13: Conn_01x03; PinHeader_1x03_P2.54mm_Vertical
J_USB_C_EXTENSION1: USB_C_Receptacle_USB2.0_16P; USB_C_Receptacle_HRO_TYPE-C-31-M-12; LCSC C165948
R36, R37: 5.1k; R_0603_1608Metric; LCSC C23186
SW1: SW_SPST; SW_Tactile_SKHH_Angled
U3: Pico; RaspberryPi_Pico_Common_Unspecified

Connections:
+5V: U3.39 (VSYS); also elsewhere on the board
/GPIO_2: U3.4 (GPIO2); also elsewhere on the board
/GPIO_3: U3.5 (GPIO3); also elsewhere on the board
/GPIO_4: U3.6 (GPIO4); also elsewhere on the board
/GPIO_5: U3.7 (GPIO5); also elsewhere on the board
/GPIO_6: U3.9 (GPIO6); also elsewhere on the board
/GPIO_7: U3.10 (GPIO7); also elsewhere on the board
/GPIO_8: U3.11 (GPIO8); also elsewhere on the board
/GPIO_9: U3.12 (GPIO9); also elsewhere on the board
/GPIO_16: U3.22 (GPIO17); also elsewhere on the board
/GPIO_17: U3.21 (GPIO16); also elsewhere on the board
/GPIO_26: U3.31 (GPIO26_ADC0); also elsewhere on the board
/GPIO_27: U3.32 (GPIO27_ADC1); also elsewhere on the board
/GPIO_28: U3.34 (GPIO28_ADC2); also elsewhere on the board
/MCU/TP1: J13.3, J_USB_C_EXTENSION1.A1 (GND), J_USB_C_EXTENSION1.A12 (GND), J_USB_C_EXTENSION1.B1 (GND), J_USB_C_EXTENSION1.B12 (GND), U3.44 (TP1)
/MCU/TP2: J13.1, J_USB_C_EXTENSION1.A7 (D-), J_USB_C_EXTENSION1.B7 (D-), U3.45 (TP2)
/MCU/TP3: J13.2, J_USB_C_EXTENSION1.A6 (D+), J_USB_C_EXTENSION1.B6 (D+), U3.46 (TP3)
/MCU/TP6: J11.1, SW1.1 (A), U3.47 (TP6)
/MCU/UART_RX: U3.2 (GPIO1); also elsewhere on the board
/MCU/UART_TX: U3.1 (GPIO0); also elsewhere on the board
BTN_1: U3.24 (GPIO18); also elsewhere on the board
BTN_2: U3.25 (GPIO19); also elsewhere on the board
BTN_3: U3.26 (GPIO20); also elsewhere on the board
BTN_LED_1: U3.27 (GPIO21); also elsewhere on the board
LED_1: U3.14 (GPIO10); also elsewhere on the board
LED_2: U3.15 (GPIO11); also elsewhere on the board
LED_3: U3.16 (GPIO12); also elsewhere on the board
LED_4: U3.17 (GPIO13); also elsewhere on the board
LED_5: U3.19 (GPIO14); also elsewhere on the board
LED_6: U3.20 (GPIO15); also elsewhere on the board
unnamed: J_USB_C_EXTENSION1.A5 (CC1), R36.1
unnamed: J_USB_C_EXTENSION1.B5 (CC2), R37.1
unnamed: J_USB_C_EXTENSION1.A4 (VBUS), J_USB_C_EXTENSION1.A9 (VBUS), J_USB_C_EXTENSION1.B4 (VBUS), J_USB_C_EXTENSION1.B9 (VBUS), U3.40 (VBUS)

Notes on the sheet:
TP2 — USB- (USB Minus) TP3 — USB+ (USB Plus) TP1 - GND
Solder these to TP's on the Raspberry Pi Pico:

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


Board: 2 copper layers, 60.5 x 110.0 mm, 98 parts (2 on the bottom side), 83 nets.

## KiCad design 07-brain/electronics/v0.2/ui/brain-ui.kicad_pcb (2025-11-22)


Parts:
H1, H2, H3, H4: MountingHole; MountingHole_3.2mm_M3_DIN965_Pad
J1: Conn_02x03_Odd_Even; PinSocket_2x03_P2.54mm_Vertical; Part no. 200-SSW10301TD
J2: Conn_01x02; PinSocket_1x02_P2.54mm_Vertical; Part no. 200-SSW10201TS
J3: Conn_01x02; PinSocket_1x02_P2.54mm_Vertical
J4, J6: Conn_02x02_Odd_Even; PinSocket_2x02_P2.54mm_Vertical
J5, J8: Conn_02x03_Odd_Even; PinSocket_2x03_P2.54mm_Vertical
J7: Conn_02x05_Odd_Even; PinSocket_2x05_P2.54mm_Vertical
J_AUDIO_CV_IN1, J_AUDIO_CV_IN2: PJ398SM; Jack_3.5mm_QingPu_WQP-PJ398SM_Vertical_CircularHoles; Part no. PJ398SM
J_AUDIO_CV_OUT1, J_AUDIO_CV_OUT2: PJ398SM; Jack_3.5mm_QingPu_WQP-PJ398SM_Vertical_CircularHoles; Part no. PJ398SM
J_MIDI1: PJ398SM-STEREO; Jack_3.5mm_QingPu_WQP-PJ398SM_Vertical_CircularHoles; Part no. PJ398SM
J_PULSE_IN1: PJ398SM; Jack_3.5mm_QingPu_WQP-PJ398SM_Vertical_CircularHoles; Part no. PJ398SM
J_PULSE_OUT1: PJ398SM; Jack_3.5mm_QingPu_WQP-PJ398SM_Vertical_CircularHoles; Part no. PJ398SM
R1: 470; R_Axial_DIN0207_L6.3mm_D2.5mm_P7.62mm_Horizontal
RV_POT1, RV_POT2: 100k; Potentiometer_Bourns_Single-PTV09A; Part no. 652-PTV09A4025FB104
U_BTN1: SW_SPST_Push_LED; SPST_Circular_Pushbutton_LED
U_BTN2, U_BTN3: SW_SPST_Push; SPST_Circular_Pushbutton_LED

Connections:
+3.3V: J3.2, RV_POT1.3, RV_POT2.3
+12V: J1.2, J3.1; also elsewhere on the board
-12V: J1.5
AUDIO_CV_IN_1: J7.6, J_AUDIO_CV_IN1.T
AUDIO_CV_IN_2: J7.10, J_AUDIO_CV_IN2.T
AUDIO_CV_OUT_1: J8.5, J_AUDIO_CV_OUT1.T
AUDIO_CV_OUT_2: J8.2, J_AUDIO_CV_OUT2.T
BTN_1: J4.1, U_BTN1.2
BTN_2: J4.3, U_BTN2.2
BTN_3: J4.2, U_BTN3.2
BTN_LED_1: J4.4, R1.1
GND: J1.1, J1.3, J1.4, J1.6, J2.1, J2.2, J8.1, J8.3, J8.4, J8.6, J_AUDIO_CV_IN1.S, J_AUDIO_CV_IN2.S, J_AUDIO_CV_OUT1.S, J_AUDIO_CV_OUT2.S, J_MIDI1.S, J_PULSE_IN1.S, J_PULSE_OUT1.S, RV_POT1.1, RV_POT2.1, U_BTN1.4, U_BTN1.L2, U_BTN2.4, U_BTN2.L2, U_BTN3.4, U_BTN3.L2; also elsewhere on the board
LED_1: J5.1; also elsewhere on the board
LED_2: J5.3; also elsewhere on the board
LED_3: J5.5; also elsewhere on the board
LED_4: J5.6; also elsewhere on the board
LED_5: J5.4; also elsewhere on the board
LED_6: J5.2; also elsewhere on the board
MIDI_4R: J6.3, J_MIDI1.TN
MIDI_5T: J6.1, J_MIDI1.T
unnamed: R1.2, U_BTN1.L1
POT_1: J7.3, RV_POT1.2
POT_2: J7.1, RV_POT2.2
PULSE_IN: J6.2, J_PULSE_IN1.T
PULSE_OUT: J6.4, J_PULSE_OUT1.T

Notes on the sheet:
UI power connection


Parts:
D1, D2, D3, D4, D5, D6: LED; LED_D3.0mm
Q1, Q2, Q3, Q4, Q5, Q6: 2N3904; TO-92_Inline_Wide
R3, R4, R7, R8, R11, R12: 47k; R_Axial_DIN0207_L6.3mm_D2.5mm_P7.62mm_Horizontal; LCSC C25803
R5, R6, R9, R10, R13, R14: 4.7k; R_Axial_DIN0207_L6.3mm_D2.5mm_P7.62mm_Horizontal

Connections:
+12V: R5.2, R6.2, R9.2, R10.2, R13.2, R14.2; also elsewhere on the board
GND: Q1.1 (E), Q2.1 (E), Q3.1 (E), Q4.1 (E), Q5.1 (E), Q6.1 (E); also elsewhere on the board
LED_1: R3.1; also elsewhere on the board
LED_2: R7.1; also elsewhere on the board
LED_3: R11.1; also elsewhere on the board
LED_4: R4.1; also elsewhere on the board
LED_5: R8.1; also elsewhere on the board
LED_6: R12.1; also elsewhere on the board
unnamed: D1.2 (A), R5.1
unnamed: D1.1 (K), Q1.3 (C)
unnamed: D2.2 (A), R9.1
unnamed: D2.1 (K), Q2.3 (C)
unnamed: D3.2 (A), R13.1
unnamed: D3.1 (K), Q3.3 (C)
unnamed: D4.2 (A), R6.1
unnamed: D4.1 (K), Q4.3 (C)
unnamed: D5.2 (A), R10.1
unnamed: D5.1 (K), Q5.3 (C)
unnamed: D6.2 (A), R14.1
unnamed: D6.1 (K), Q6.3 (C)
unnamed: Q1.2 (B), R3.2
unnamed: Q2.2 (B), R7.2
unnamed: Q3.2 (B), R11.2
unnamed: Q4.2 (B), R4.2
unnamed: Q5.2 (B), R8.2
unnamed: Q6.2 (B), R12.2



Board: 2 copper layers, 58.0 x 110.0 mm, 49 parts (7 on the bottom side), 42 nets.

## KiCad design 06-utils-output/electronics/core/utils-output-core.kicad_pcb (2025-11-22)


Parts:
H1, H2, H3, H4: MountingHole; MountingHole_3.2mm_M3_DIN965_Pad
J1: Conn_01x06; PinHeader_1x06_P2.54mm_Vertical
J4: Conn_02x04_Odd_Even; PinHeader_2x04_P2.54mm_Vertical
J5: Conn_02x03_Odd_Even; PinHeader_2x03_P2.54mm_Vertical
J6: Conn_02x05_Odd_Even; PinHeader_2x05_P2.54mm_Vertical

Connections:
CRUSH_IN: J4.2; also elsewhere on the board
CRUSH_OUT: J4.1; also elsewhere on the board
CRUSH_TRIG: J4.3; also elsewhere on the board
CRUSH_TRIG_DEFAULT: J4.4; also elsewhere on the board
GND: J4.8, J5.4, J6.6, J6.8, J6.10; also elsewhere on the board
LFO_POT_1: J5.3; also elsewhere on the board
LFO_POT_2: J5.5; also elsewhere on the board
LFO_POT_3: J5.6; also elsewhere on the board
LFO_SQR: J5.1; also elsewhere on the board
LFO_TRI: J5.2; also elsewhere on the board
OUTPUT_DRIVE_1: J6.3; also elsewhere on the board
OUTPUT_DRIVE_3: J6.1; also elsewhere on the board
OUTPUT_IN: J6.7; also elsewhere on the board
OUTPUT_LINE_OUT: J6.9; also elsewhere on the board
OUTPUT_PHONES_OUT: J6.5; also elsewhere on the board
OUTPUT_VOL_2: J6.4; also elsewhere on the board
OUTPUT_VOL_3: J6.2; also elsewhere on the board
RV_CRUSH_1: J4.5; also elsewhere on the board
RV_CRUSH_2: J4.7; also elsewhere on the board
RV_CRUSH_3: J4.6; also elsewhere on the board

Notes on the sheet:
Power
LFO_TRI
CRUSH_OUT
Shielding pairs DO NOT GROUND ON UI BOARD!
Default patch connector
LFO_SQR
Modules
CRUSH_IN
I/O
OUTPUT_IN


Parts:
C201, C202: 100n; C_0603_1608Metric; LCSC C14663
C203: 3.3n (foil); C_Rect_L7.0mm_W2.5mm_P5.00mm; Part No. 80-R82EC1330AA50K
R201: 5.1M; R_0603_1608Metric; LCSC C13320
R202: 200k; R_0603_1608Metric; LCSC C25811
R203: 15k; R_0603_1608Metric; LCSC C25811
R204: 470k; R_0603_1608Metric; LCSC C23178
R205: 100k; R_0603_1608Metric; LCSC C25803
R206: 220; R_Axial_DIN0207_L6.3mm_D2.5mm_P7.62mm_Horizontal
R207: 12k; R_0603_1608Metric; LCSC C22962
R208, R212: 1k; R_0603_1608Metric; LCSC C21190
R209: 1M; R_0603_1608Metric; LCSC C22935
R210: 2k; R_0603_1608Metric; LCSC C25811
R211: 10k; R_0603_1608Metric; LCSC C22962
U201: TL072; SOIC-8_3.9x4.9mm_P1.27mm; LCSC C6961

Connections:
GND: C201.2, C202.1, R206.2, R207.2, R211.2, U201.2 (-), U201.5 (+); also elsewhere on the board
LFO_POT_1: R206.1; also elsewhere on the board
LFO_POT_2: R209.2; also elsewhere on the board
LFO_POT_3: R204.1; also elsewhere on the board
LFO_SQR: R208.2; also elsewhere on the board
LFO_TRI: R212.2; also elsewhere on the board
unnamed: C203.1, R205.2, R210.1, U201.7
unnamed: R202.2, R203.1, R204.2, U201.1
unnamed: R203.2, R207.1, R208.1
unnamed: R210.2, R211.1, R212.1
unnamed: R201.2, R202.1, R205.1, U201.3 (+)
unnamed: C203.2, R209.1, U201.6 (-)

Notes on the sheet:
Pot: A500k


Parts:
C10, C11, C12, C13: 100n; C_0603_1608Metric; LCSC C14663
C14: 10u; CP_Elec_5x5.4; LCSC C4747971
C15: 100p; C_0603_1608Metric; LCSC C14858
D15, D16: 1N4148; D_SOD-123; LCSC C81598
D_LIM_N1: Red LED; LED_D3.0mm
D_LIM_P1: Red LED; LED_D5.0mm
R11: 4.7k; R_0603_1608Metric; LCSC C23162
R12: 150; R_0603_1608Metric; LCSC C22808
R13, R25: 1k; R_0603_1608Metric; LCSC C21190
R14, R15: 100; R_0603_1608Metric; LCSC C22775
R24: 22k; R_0603_1608Metric; LCSC C31850
R29: 10k; R_0603_1608Metric; LCSC C25804
RV_LINE_OUT_LVL1: 10k; Potentiometer_ACP_CA6-H2,5_Horizontal; Part No. 531-PT6KH-10K
TP1: MAX_LINEOUT; TestPoint_THTPad_D1.5mm_Drill0.7mm
TP2: MAINOUT; TestPoint_THTPad_2.0x2.0mm_Drill1.0mm
TP3: PHONES_OUT; TestPoint_THTPad_2.0x2.0mm_Drill1.0mm
U4: NE5532; SOIC-8_3.9x4.9mm_P1.27mm; LCSC C7426
U5: TL072; SOIC-8_3.9x4.9mm_P1.27mm; LCSC C6961

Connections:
GND: C10.2, C11.1, C12.2, C13.1, D_LIM_N1.2 (A), D_LIM_P1.1 (K), R24.1, RV_LINE_OUT_LVL1.1; also elsewhere on the board
unnamed: C14.1, RV_LINE_OUT_LVL1.2, TP1.1
unnamed: C14.2, R29.2
unnamed: C15.2, D15.2 (A), D16.1 (K), R11.1, R12.1, R13.1, U4.3 (+)
unnamed: R12.2, U5.7
unnamed: R15.2, U4.1, U4.2 (-), U4.5 (+)
unnamed: R14.2, U4.6 (-), U4.7
unnamed: C15.1, R11.2, U5.6 (-)
OUTPUT_DRIVE_1: R24.2, U5.2 (-); also elsewhere on the board
OUTPUT_DRIVE_3: R25.2, U5.1; also elsewhere on the board
OUTPUT_IN: RV_LINE_OUT_LVL1.3; also elsewhere on the board
OUTPUT_LINE_OUT: R13.2, TP2.1; also elsewhere on the board
OUTPUT_PHONES_OUT: R14.1, R15.1, TP3.1; also elsewhere on the board
OUTPUT_VOL_2: U5.5 (+); also elsewhere on the board
OUTPUT_VOL_3: D_LIM_N1.1 (K), D_LIM_P1.2 (A), R25.1; also elsewhere on the board

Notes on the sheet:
Vol pot (log): it's buffered so size should have no effect on output impedance.
5.5x gain
Proto this! If works, replace with SMD variant.
Max line out level Set to 2.8Vpp
10Vpp


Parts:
C8, C9: 100u; CP_Elec_6.3x7.7; LCSC C2836437
D1, D2: 1N5817; D_SOD-323; LCSC C5190152
J2: Conn_02x03_Odd_Even; PinHeader_2x03_P2.54mm_Vertical
J3: Conn_01x02; PinHeader_1x02_P2.54mm_Vertical
J7: Conn_02x05_Odd_Even; IDC-Header_2x05_P2.54mm_Horizontal

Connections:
GND: C8.2, C9.1, J2.1, J2.3, J2.4, J2.6, J3.1, J3.2, J7.3, J7.4, J7.5, J7.6, J7.7, J7.8; also elsewhere on the board
unnamed: D1.2 (A), J7.9, J7.10
unnamed: D2.1 (K), J7.1, J7.2

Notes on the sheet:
UI power connection
Eurorack PSU connection


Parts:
C1, C2, C3, C4: 100n; C_0603_1608Metric; LCSC C14663
C16, C17: 100n (foil); C_Rect_L7.2mm_W2.5mm_P5.00mm_FKS2_FKP2_MKS2_MKP2
C18: 1n (foil); C_Rect_L7.2mm_W2.5mm_P5.00mm_FKS2_FKP2_MKS2_MKP2
D3, D4: 1N4148; D_SOD-123; LCSC C81598
Q2: 2N3819; TO-92_Inline_Wide
R1: 33k; R_0603_1608Metric; LCSC C4216
R10, R18: 10k; R_0603_1608Metric; LCSC C25804
R16: 1M; R_0603_1608Metric; LCSC C22935
R17: 1k; R_0603_1608Metric; LCSC C21190
R19, R21, R22, R23: 100k; R_0603_1608Metric; LCSC C25803
R20: 4.7k; R_0603_1608Metric; LCSC C23162
U1, U2: TL072; SOIC-8_3.9x4.9mm_P1.27mm; LCSC C6961

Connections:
CRUSH_IN: R10.1; also elsewhere on the board
CRUSH_OUT: R17.2; also elsewhere on the board
CRUSH_TRIG: C18.1; also elsewhere on the board
CRUSH_TRIG_DEFAULT: R18.2, R19.2, U2.1; also elsewhere on the board
GND: C1.2, C2.1, C3.2, C4.1, C16.2, C17.2, R1.1, R20.1, R21.1, R23.1; also elsewhere on the board
unnamed: C18.2, D3.2 (A), R21.2
unnamed: D3.1 (K), R23.2, U2.5 (+)
unnamed: D4.2 (A), Q2.2 (G), R16.1
unnamed: D4.1 (K), U2.7
unnamed: Q2.1 (D), R16.2, U1.1, U1.2 (-)
unnamed: C16.1, Q2.3 (S), U1.5 (+)
unnamed: C17.1, R18.1, U2.2 (-)
unnamed: R1.2, R22.1, U2.6 (-)
RV_CRUSH_1: R20.2; also elsewhere on the board
RV_CRUSH_2: U2.3 (+); also elsewhere on the board
RV_CRUSH_3: R19.1; also elsewhere on the board

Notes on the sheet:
Relaxation oscillator
S&H notes Aug 20 2025: - tested, works - 2N3819 is significantly better for bitcrusher (audio) than other JFET's (e.g. J112)
Oscillator notes Aug 20 2025 - tested, works Frequency range: - with A500k crush pot -> 210Hz - 15kHz - with A1M crush pot -> 160Hz - 19kHz (better)

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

Board: 2 copper layers, 58.0 x 65.0 mm, 77 parts (0 on the bottom side), 48 nets.

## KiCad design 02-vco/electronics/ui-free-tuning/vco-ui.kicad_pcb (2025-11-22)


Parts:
H1, H2, H3, H4, H5: MountingHole; MountingHole_3.2mm_M3_DIN965_Pad
J1: Conn_01x04; PinSocket_1x04_P2.54mm_Vertical; Part no. 200-SSW10401TMS
J2: Conn_02x05_Odd_Even; PinSocket_2x05_P2.54mm_Vertical; Part no. 200-SSW10501TD
J3: Conn_02x03_Odd_Even; PinSocket_2x03_P2.54mm_Vertical; Part no. 200-SSW10301TD
J4: Conn_01x02; PinSocket_1x02_P2.54mm_Vertical; Part no. 200-SSW10201TS
J5: Conn_02x02_Counter_Clockwise; PinSocket_2x02_P2.54mm_Vertical; Part no. 200-SSW10206TD
J6: Conn_01x07; PinSocket_1x07_P2.54mm_Vertical; Part no. 200-SSW10601TS
JP1: Jumper_3_Open; PinHeader_1x03_P2.54mm_Horizontal; Part no. 200-HTSW10308TSRA
JP2, JP3: Jumper_2_Open; PinHeader_1x02_P2.54mm_Horizontal; Part no. 200-HTSW10208TSRA
J_CV1: PJ398SM; Jack_3.5mm_QingPu_WQP-PJ398SM_Vertical_CircularHoles; Part no. PJ398SM
J_EXTRA_OUT1: PJ398SM; Jack_3.5mm_QingPu_WQP-PJ398SM_Vertical_CircularHoles; Part no. PJ398SM
J_FM1: PJ398SM; Jack_3.5mm_QingPu_WQP-PJ398SM_Vertical_CircularHoles; Part no. PJ398SM
J_OUT1: PJ398SM; Jack_3.5mm_QingPu_WQP-PJ398SM_Vertical_CircularHoles; Part no. PJ398SM
J_PWM1: PJ398SM; Jack_3.5mm_QingPu_WQP-PJ398SM_Vertical_CircularHoles; Part no. PJ398SM
J_SYNC1: PJ398SM; Jack_3.5mm_QingPu_WQP-PJ398SM_Vertical_CircularHoles; Part no. PJ398SM
R1: 130k; R_Axial_DIN0207_L6.3mm_D2.5mm_P7.62mm_Horizontal
R2, R3, R6: 100k; R_Axial_DIN0207_L6.3mm_D2.5mm_P7.62mm_Horizontal; Part no. 603-MFR-25FRF52100K
R4, R5: 510k; R_Axial_DIN0207_L6.3mm_D2.5mm_P7.62mm_Horizontal
R7, R8: 220k; R_Axial_DIN0207_L6.3mm_D2.5mm_P7.62mm_Horizontal; Part no. 603-MFR-25FRF52-220K
RV_FINE1: 100k; Potentiometer_Bourns_Single-PTV09A; Part no. 652-PTV09A4025FB104
RV_PWM1: 100k; Potentiometer_Bourns_Single-PTV09A; Part no. 652-PTV09A4025FB104
RV_TUNE1: 100k; Potentiometer_Bourns_Single-PTV09A; Part no. 652-PTV09A4025FB104
U1: 0203; SR1712-0203; Part no. 105-SR1712F-23NS

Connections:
+12V: J3.2, R1.1, R4.1, RV_PWM1.3
-12V: J3.5, R5.2, RV_PWM1.1
CV: J1.1, R2.2, R3.2, R6.2
CV_DEFAULT: J6.4, JP3.1 (A), J_CV1.TN
CV_INPUT: J6.6, J_CV1.T, R3.1
EXTRA_DEFAULT: J6.5, J_EXTRA_OUT1.TN
FM: J1.3, J_FM1.T
FM_DEFAULT: J6.2, JP2.1 (A), J_FM1.TN
GND: J3.1, J3.3, J3.4, J3.6, J4.1, J4.2, JP2.2 (B), JP3.2 (B), J_CV1.S, J_EXTRA_OUT1.S, J_FM1.S, J_OUT1.S, J_PWM1.S, J_SYNC1.S, RV_TUNE1.1
HARD_SYNC: J1.2, J_SYNC1.T
NOISE: J5.1, JP1.1 (A)
unnamed: JP1.2 (C), J_EXTRA_OUT1.T
unnamed: J_OUT1.T, U1.1
unnamed: J_PWM1.T, R8.1
unnamed: R1.2, RV_TUNE1.3
unnamed: R2.1, RV_TUNE1.2
unnamed: R4.2, RV_FINE1.3
unnamed: R5.1, RV_FINE1.1
unnamed: R6.1, RV_FINE1.2
unnamed: R7.1, RV_PWM1.2
OUT_DEFAULT: J6.7, J_OUT1.TN
PWM_DEFAULT: J6.3, J_PWM1.TN
SAW: J2.7, U1.3
SQR: J2.3, U1.4
SQR_SHAPE: J1.4, R7.2, R8.2
SUB: J5.3, JP1.3 (B)
SYNC_DEFAULT: J6.1, J_SYNC1.TN
TRI: J2.5, U1.2

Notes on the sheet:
@TODO: check jack normalization
Use these jumpers to ground critical default inputs to ground if needed.
UI power connection
Use jumper to select noise or sub to output on the extra out jack.
Shielding pairs DO NOT GROUND ON UI BOARD!



Board: 2 copper layers, 58.0 x 110.0 mm, 32 parts (5 on the bottom side), 28 nets.

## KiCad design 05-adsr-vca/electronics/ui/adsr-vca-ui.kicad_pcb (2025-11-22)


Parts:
D1: Red LED; LED_D3.0mm
H1, H2, H3, H4, H5, H6: MountingHole; MountingHole_3.2mm_M3_DIN965_Pad
J1: Conn_02x03_Odd_Even; PinSocket_2x03_P2.54mm_Vertical; Part no. 200-SSW10301TD
J3, J6, J8: Conn_02x03_Odd_Even; PinSocket_2x03_P2.54mm_Vertical
J4: Conn_01x02; PinSocket_1x02_P2.54mm_Vertical; Part no. 200-SSW10201TS
J5: Conn_01x06; PinSocket_1x06_P2.54mm_Vertical; Part no. 200-SSW10601TS
JP_DEFAULT_ENV_TO_VCA1: Jumper_2_Open; PinHeader_1x02_P2.54mm_Horizontal
J_ENV_OUT1: PJ398SM; Jack_3.5mm_QingPu_WQP-PJ398SM_Vertical_CircularHoles; Part no. PJ398SM
J_GATE1: PJ398SM; Jack_3.5mm_QingPu_WQP-PJ398SM_Vertical_CircularHoles; Part no. PJ398SM
J_VCA_CV1: PJ398SM; Jack_3.5mm_QingPu_WQP-PJ398SM_Vertical_CircularHoles; Part no. PJ398SM
J_VCA_IN1: PJ398SM; Jack_3.5mm_QingPu_WQP-PJ398SM_Vertical_CircularHoles; Part no. PJ398SM
J_VCA_OUT1: PJ398SM; Jack_3.5mm_QingPu_WQP-PJ398SM_Vertical_CircularHoles; Part no. PJ398SM
Q1: 2N3904; TO-92_Inline_Wide
Q2: 2N3906; TO-92_Inline_Wide
R1: 100k; R_Axial_DIN0207_L6.3mm_D2.5mm_P7.62mm_Horizontal
R2: 47k; R_Axial_DIN0207_L6.3mm_D2.5mm_P7.62mm_Horizontal
R3: 4.7k; R_Axial_DIN0207_L6.3mm_D2.5mm_P7.62mm_Horizontal
RV_ATTACK1: A500k; Potentiometer_Bourns_Single-PTV09A; Part no. 652-PTV09A4025FB104
RV_DECAY1: A500k; Potentiometer_Bourns_Single-PTV09A; Part no. 652-PTV09A4025FB104
RV_RELEASE1: A500k; Potentiometer_Bourns_Single-PTV09A; Part no. 652-PTV09A4025FB104
RV_SUSTAIN1: 10k; TRIM_PTA4543-2015DPB103; Part no. 652-PTV09A4025FB104

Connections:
+12V: J1.2, R3.1
-12V: J1.5, Q2.3 (C)
A1_D3_R3: J8.6, RV_ATTACK1.1, RV_DECAY1.2, RV_DECAY1.3, RV_RELEASE1.2, RV_RELEASE1.3
ATTACK_3: J8.2, RV_ATTACK1.2, RV_ATTACK1.3
DECAY_1: J8.5, RV_DECAY1.1
ENV_OUT: J8.4, JP_DEFAULT_ENV_TO_VCA1.1 (A), J_ENV_OUT1.T, R2.1
ENV_OUT_DEFAULT: J5.3, J_ENV_OUT1.TN
GATE: J5.2, J8.1, J_GATE1.T
GATE_DEFAULT: J5.1, J_GATE1.TN
GND: J1.1, J1.3, J1.4, J1.6, J4.1, J4.2, J_ENV_OUT1.S, J_GATE1.S, J_VCA_CV1.S, J_VCA_IN1.S, J_VCA_OUT1.S, Q2.2 (B)
unnamed: D1.2 (A), Q1.1 (E)
unnamed: D1.1 (K), Q2.1 (E)
unnamed: J_VCA_IN1.T, R1.1
unnamed: Q1.2 (B), R2.2
unnamed: Q1.3 (C), R3.2
RELEASE_1: J8.3, RV_RELEASE1.1
SUSTAIN_1: J6.2, RV_SUSTAIN1.1
SUSTAIN_2: J6.4, RV_SUSTAIN1.2
SUSTAIN_3: J6.6, RV_SUSTAIN1.3
VCA_CV: J3.3, J_VCA_CV1.T
VCA_CV_DEFAULT: J5.5, JP_DEFAULT_ENV_TO_VCA1.2 (B), J_VCA_CV1.TN
VCA_IN: J3.5, R1.2
VCA_IN_DEFAULT: J5.4, J_VCA_IN1.TN
VCA_OUT: J3.1, J_VCA_OUT1.T
VCA_OUT_DEFAULT: J5.6, J_VCA_OUT1.TN

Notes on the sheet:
R1 is Only for testing There's a similar resistor on the core board, this one is here for testing crosstalk. If the one on the core board works, this should be shorted (and removed on the next version of this board).
UI power connection



Board: 2 copper layers, 58.0 x 110.0 mm, 28 parts (5 on the bottom side), 25 nets.

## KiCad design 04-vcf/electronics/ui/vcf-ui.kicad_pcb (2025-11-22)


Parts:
C1, C2: 100n; C_Disc_D5.0mm_W2.5mm_P2.50mm
H1, H2, H3, H4, H5, H6: MountingHole; MountingHole_3.2mm_M3_DIN965_Pad
J1: Conn_02x03_Odd_Even; PinSocket_2x03_P2.54mm_Vertical; Part no. 200-SSW10301TD
J2: Conn_02x02_Counter_Clockwise; PinSocket_2x02_P2.54mm_Vertical; Part no. 200-SSW10206TD
J4: Conn_01x02; PinSocket_1x02_P2.54mm_Vertical; Part no. 200-SSW10201TS
J5: Conn_01x06; PinSocket_1x06_P2.54mm_Vertical; Part no. 200-SSW10601TS
J6: Conn_02x04_Odd_Even; PinSocket_2x04_P2.54mm_Vertical
JP1: Jumper_3_Open; PinHeader_1x03_P2.54mm_Vertical
J_CUTOFF1, J_CUTOFF2: PJ398SM; Jack_3.5mm_QingPu_WQP-PJ398SM_Vertical_CircularHoles; Part no. PJ398SM
J_HP1: PJ398SM; Jack_3.5mm_QingPu_WQP-PJ398SM_Vertical_CircularHoles; Part no. PJ398SM
J_LP1: PJ398SM; Jack_3.5mm_QingPu_WQP-PJ398SM_Vertical_CircularHoles; Part no. PJ398SM
J_OUT1: PJ398SM; Jack_3.5mm_QingPu_WQP-PJ398SM_Vertical_CircularHoles; Part no. PJ398SM
R1: 6.8k; R_Axial_DIN0207_L6.3mm_D2.5mm_P7.62mm_Horizontal; Part no. 603-MFR-25FRF52100K
R2: 3.3k; R_Axial_DIN0207_L6.3mm_D2.5mm_P7.62mm_Horizontal; Part no. 603-MFR-25FRF52100K
R3: 220k; R_Axial_DIN0207_L6.3mm_D2.5mm_P7.62mm_Horizontal; Part no. 603-MFR-25FRF52100K
R4, R5, R10, R11: 10k-1M; R_Axial_DIN0207_L6.3mm_D2.5mm_P7.62mm_Horizontal; Part no. 603-MFR-25FRF52100K
R6, R7, R8, R12, R13, R14: 100k; R_Axial_DIN0207_L6.3mm_D2.5mm_P7.62mm_Horizontal; Part no. 603-MFR-25FRF52100K
R9: 100k; R_Axial_DIN0207_L6.3mm_D2.5mm_P7.62mm_Horizontal; Part no. 603-MFR-25FRF52-220K
RV_CUTOFF1, RV_CUTOFF2: 100k; Potentiometer_Bourns_Single-PTV09A; Part no. 652-PTV09A4025FB104
RV_CUTOFF_BIAS1: 10k; Potentiometer_ACP_CA6-H2,5_Horizontal
RV_MAIN_CUTOFF1: 100k; Potentiometer_Bourns_Single-PTV09A; Part no. 652-PTV09A4025FB104
RV_RESO1: 100k; Potentiometer_Bourns_Single-PTV09A; Part no. 652-PTV09A4025FB104
U1: TL072; DIP-8_W7.62mm_LongPads

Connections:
+12V: C1.1, J1.2, R1.1, RV_MAIN_CUTOFF1.3, U1.8 (V+)
-12V: C2.2, J1.5, JP1.1 (A), R2.1, U1.4 (V-)
CUTOFF: J6.7, R3.2, R8.2, R9.2, R14.2
CUTOFF_1_DEFAULT: J5.3, J_CUTOFF1.TN
CUTOFF_2_DEFAULT: J5.4, J_CUTOFF2.TN
GND: C1.2, C2.1, J1.1, J1.3, J1.4, J1.6, J4.1, J4.2, JP1.3 (B), J_CUTOFF1.S, J_CUTOFF2.S, J_HP1.S, J_LP1.S, J_OUT1.S, R5.1, R11.1, RV_CUTOFF1.1, RV_CUTOFF2.1, RV_RESO1.1
HP_DEFAULT: J5.1, J_HP1.TN
HP_IN: J6.5, J_HP1.T
LP_DEFAULT: J5.2, J_LP1.TN
LP_IN: J6.3, J_LP1.T
unnamed: JP1.2 (C), RV_MAIN_CUTOFF1.1
unnamed: J_CUTOFF1.T, R4.2, R6.1, RV_CUTOFF1.3
unnamed: J_CUTOFF2.T, R10.2, R12.1, RV_CUTOFF2.3
unnamed: R1.2, RV_CUTOFF_BIAS1.3
unnamed: R2.2, RV_CUTOFF_BIAS1.1
unnamed: R3.1, RV_CUTOFF_BIAS1.2
unnamed: R7.2, R8.1, U1.1
unnamed: R9.1, RV_MAIN_CUTOFF1.2
unnamed: R13.2, R14.1, U1.7
unnamed: R4.1, R5.2, RV_CUTOFF1.2, U1.3 (+)
unnamed: R6.2, R7.1, U1.2 (-)
unnamed: R10.1, R11.2, RV_CUTOFF2.2, U1.5 (+)
unnamed: R12.2, R13.1, U1.6 (-)
OUT: J6.2, J_OUT1.T
OUT_DEFAULT: J5.5, J_OUT1.TN
RESO_MAX: J2.1, RV_RESO1.3
RESO_VALUE: J2.3, RV_RESO1.2

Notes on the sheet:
UI power connection
Adjust resistors for logarithmic curve of the attenuverter: 10k — logarithmic 1M — close to linear Around 47k is a pretty sweet spot.
Shielding pairs DO NOT GROUND ON UI BOARD!
Adjust resistors for logarithmic curve of the attenuverter: 10k - logarithmic 1M - close to linear Around 47k is a pretty sweet spot.



Board: 2 copper layers, 58.0 x 110.0 mm, 39 parts (4 on the bottom side), 27 nets.

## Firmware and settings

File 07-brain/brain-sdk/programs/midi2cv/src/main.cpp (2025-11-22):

// MIDI → CV main program: maps MIDI notes to 1 V/oct CV on DAC A
// Dependencies: brain-io (MidiParser, AudioCvOut, Pulse), brain-common pins
// Hardware notes: MCP4822 on SPI; PULSE output is hardware-inverted (handled by Pulse)
// Owner: midi2cv app

#include <pico/stdlib.h>
#include <stdint.h>

#include <cstdio>
#include <optional>

#include "brain-common/brain-common.h"
#include "brain-io/audio-cv-out.h"
#include "brain-io/midi-parser.h"
#include "brain-io/pulse.h"
#include "brain-ui/led.h"
#include "config.h"
#include "cv-mapper.h"
#include "note-stack.h"

using brain::io::AudioCvOut;
using brain::io::AudioCvOutChannel;
using brain::io::MidiParser;
using brain::io::Pulse;
using brain::ui::Led;

// Global singletons for callbacks (program scope)
static AudioCvOut g_dac;
static Pulse g_gate;  // uses default Brain PULSE pins
static NoteStack g_stack;
static CvMapper g_cv_mapper;
static Led g_led(BRAIN_LED_1);

constexpr uint LED_PINS[] = {
	BRAIN_LED_1, BRAIN_LED_2, BRAIN_LED_3, BRAIN_LED_4, BRAIN_LED_5, BRAIN_LED_6};
constexpr uint NUM_LEDS = 6;

static inline void applyCurrentNoteCv();

// Debug logging (disable for production to prevent MIDI event drops due to printf blocking)
// Set to 1 to see Note On/Off events (useful for debugging)
// Set to 0 for production (prevents printf blocking that can drop MIDI events)
#define DEBUG_MIDI_EVENTS 0

// MIDI callbacks (C-style function pointers)
static void onNoteOn(uint8_t note, uint8_t velocity, uint8_t channel) {
	(void) velocity;
	(void) channel;
#if DEBUG_MIDI_EVENTS
	printf("[NoteON ] note=%u vel=%u ch=%u\r\n", note, velocity, channel);
#endif
	g_stack.pushTop(note);
	g_gate.set(true);  // logical HIGH (Pulse handles hardware inversion)
	g_led.on();
	applyCurrentNoteCv();
}

static void onNoteOff(uint8_t note, uint8_t velocity, uint8_t channel) {
	(void) velocity;
	(void) channel;
#if DEBUG_MIDI_EVENTS
	printf("[NoteOFF] note=%u vel=%u ch=%u\r\n", note, velocity, channel);
#endif
	g_stack.remove(note);
	if (g_stack.isEmpty()) {
		// No active note -> gate LOW, hold last CV
		g_gate.set(false);
		g_led.off();
	} else {
		applyCurrentNoteCv();
	}
}

static inline void applyCurrentNoteCv() {
	auto top = g_stack.topOrNone();
	float volts = 0.0f;
	if (top.has_value()) {
		volts = g_cv_mapper.noteToVolts(top.value());
	}
	// Clamp to supported range [0, 10]
	if (volts < 0.0f) volts = 0.0f;
	if (volts > 10.0f) volts = 10.0f;

	// NOTE: printf() in callback hot path causes blocking that can drop MIDI events
	// Uncomment for debugging only, not for production use
	// printf("\r\n Volt: %f", volts);

	g_dac.setVoltage(AudioCvOutChannel::kChannelA, volts);
}

int main() {
	stdio_init_all();

	sleep_ms(1000);

	// Initialize DAC (SPI pins from Brain defaults). Force DC coupling and 0V on both.
	if (!g_dac.init()) {
		fprintf(stderr, "midi2cv: DAC init failed\n");
	}
	g_dac.setCoupling(AudioCvOutChannel::kChannelA, brain::io::AudioCvOutCoupling::kDcCoupled);
	g_dac.setCoupling(AudioCvOutChannel::kChannelB, brain::io::AudioCvOutCoupling::kDcCoupled);
	g_dac.setVoltage(AudioCvOutChannel::kChannelA, 0.0f);
	g_dac.setVoltage(AudioCvOutChannel::kChannelB, 0.0f);

	// Initialize Gate output (default Pulse pins).
	g_gate.begin();
	g_gate.set(false);	// LOW at startup

	// Configure MIDI parser
	MidiParser parser(config::kMidiChannel, config::kOmniMode);
	parser.setNoteOnCallback(&onNoteOn);
	parser.setNoteOffCallback(&onNoteOff);
	if (!parser.initUart()) {
		fprintf(stderr, "midi2cv: MIDI UART init failed\n");
	}

	printf("midi2cv: ready (ch=%u, omni=%d)\n", parser.channel(), parser.omni());

	// Initialize all LEDs
	brain::ui::Led leds[NUM_LEDS] = {brain::ui::Led(LED_PINS[0]), brain::ui::Led(LED_PINS[1]),
		brain::ui::Led(LED_PINS[2]), brain::ui::Led(LED_PINS[3]), brain::ui::Led(LED_PINS[4]),
		brain::ui::Led(LED_PINS[5])};

	// Reset all LEDs to off
	printf("Resetting all LEDs to OFF\n");
	for (uint i = 0; i < NUM_LEDS; i++) {
		leds[i].init();
		leds[i].off();
	}
	sleep_ms(200);

	// Running lights effect to show successful startup
	printf("Running startup LED sequence\n");
	for (uint i = 0; i < NUM_LEDS; i++) {
		leds[i].on();
		sleep_ms(100);
		leds[i].off();
	}
	sleep_ms(200);

	// Flash all LEDs twice to confirm ready
	for (uint flash = 0; flash < 2; flash++) {
		for (uint i = 0; i < NUM_LEDS; i++) {
			leds[i].on();
		}
		sleep_ms(150);
		for (uint i = 0; i < NUM_LEDS; i++) {
			leds[i].off();
		}
		sleep_ms(150);
	}

	g_led.init();

	// Main loop: process UART MIDI and dispatch via callbacks
	while (true) {
		parser.processUartInput();
		tight_loop_contents();
	}

	return 0;
}

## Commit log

2025-06-01 Added temporary frame enclosure
    We needed a temporary enclosure, a frame to hold the modules in while we're working on them.
    [Hog Moduleur ER-Frame - Joint.stl, Hog Moduleur ER-Frame - Rail.stl, Hog Moduleur ER-Frame - Small Stand.stl]
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2025-06-09 Added PSU schematics and PCB (v1.0)
    [psu.kicad_pcb, psu.kicad_sch]
2025-06-09 Added protection diode and terminal to PSU
    [psu.kicad_pcb, psu.kicad_sch]
2025-06-09 Moved current PSU to Eurorack folder2
    [psu.kicad_pcb, psu.kicad_sch]
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2025-06-15 Added leds to psu
    [psu.kicad_pcb, psu.kicad_sch]
2025-06-15 Added PSU BOM and gerber
    [psu-bom.csv, psu.kicad_pcb, psu.kicad_sch]
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2025-07-04 Designed VCO core PCB
    [power.kicad_sch, raw-oscillator.kicad_sch, vco-core.kicad_pcb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]
2025-07-04 Added whaveshapers to VCO PCB
    [vco-core.kicad_pcb, vco-core.kicad_sch]
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2025-07-04 Finished VCO Core PCB v0.1
    [vco-core.kicad_pcb]
2025-07-04 Added mounting holes to VCO Core PCB
    [vco-core.kicad_pcb]
2025-07-04 Added 2-layer version of VCO Core PCB
    [bom.csv, designators.csv, positions.csv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]
2025-07-04 Added test production files
    [bom.csv, designators.csv, positions.csv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]
2025-07-04 Deleted 4-layer VCO Core PCB
    [bom.csv, designators.csv, positions.csv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]
2025-07-04 Updated tooling holes on VCO Core PCB
    [bom.csv, designators.csv, positions.csv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]
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2025-07-05 Added sub & noise circuit to VCO core
    [sub+noise.kicad_sch, vco-core.kicad_pcb, vco-core.kicad_sch]
2025-07-05 Adjusted screw position and tuning copy on VCO core
    [vco-core.kicad_pcb]
2025-07-05 Added AC coupling to noise and sub + 1k outputs
    [sub+noise.kicad_sch, vco-core.kicad_pcb, waveshapers.kicad_sch]
2025-07-05 Added reverse polarity protection VCO core
    [power.kicad_sch, vco-core.kicad_pcb]
2025-07-06 Updated noise+sub AC coupling in VCO core
    [power.kicad_sch, sub+noise.kicad_sch, vco-core.kicad_pcb]
2025-07-06 Refined VCO core back silkscreen
    [vco-core.kicad_pcb]
2025-07-06 Repositioned grid origin VCO core PCB
    [vco-core.kicad_pcb]
2025-07-06 Added VCO UI board
    [vco-core.kicad_pcb, vco-ui.kicad_pcb, vco-ui.kicad_sch]
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2025-07-06 Added VCO UI Plot PDF
    [vco-ui.kicad_pcb]
2025-07-11 Added default IO conn. to VCO core
    [power.kicad_sch, vco-core.kicad_pcb, vco-core.kicad_sch]
2025-07-11 Updated VCO core to use pin headers not sockets
    [power.kicad_sch, vco-core.kicad_pcb, vco-core.kicad_sch]
2025-07-12 Added default IO to VCO UI board
    [vco-core.kicad_pcb, vco-ui.kicad_pcb, vco-ui.kicad_sch]
2025-07-12 Fixed VCO UI component orientations
    - Wave selector rotary switch had to be rotated
    - Polarity of all pots was reversed
    [vco-ui.kicad_pcb, vco-ui.kicad_sch]
2025-07-13 Refined VCO core and UI
    [bom.csv, designators.csv, positions.csv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]
2025-07-15 0.1 design of Sidechain Mixer
    [power.kicad_sch, sc-mixer.kicad_sch, sidechain-mixer.kicad_pcb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]
2025-07-16 Cleanup before PCB order
    [bom.csv, designators.csv, positions.csv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]
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2025-07-17 Finished v0.1 of VCF PCB
    [vcf.kicad_pcb, vcf.kicad_sch]
2025-07-18 Designed UI schematics for VCF
    [sidechain-mixer-core.kicad_pcb, sidechain-mixer-core.kicad_sch, sidechain-mixer-ui.kicad_pcb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]
2025-07-19 Designed VCF UI board pre-check
    [vcf-core.kicad_pcb, vcf-core.kicad_sch, vcf-ui.kicad_pcb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]
2025-07-19 Added production files to VCF core
    [bom.csv, designators.csv, positions.csv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]
2025-07-19 V0.1 VCF PCB checked and ready for prod
    [bom.csv, designators.csv, positions.csv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]
2025-07-19 VCF v0.1 proto ordered
    [vcf-core.kicad_pcb, vcf-ui.kicad_pcb]
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2025-07-29 Updated sidechain mixer schematics
    [sc-mixer.kicad_sch, sidechain-mixer-core.kicad_sch]
2025-07-29 Prepared sidechain mixer PCB
    [power.kicad_sch, sc-mixer.kicad_sch, sidechain-mixer-core.kicad_pcb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]
2025-07-31 Fixed VCF v0.1 bugs - new version: v0.2
    [bom.csv, designators.csv, positions.csv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]
2025-08-01 SC-Mixer PCB base done
    [power.kicad_sch, sc-mixer.kicad_sch, sidechain-mixer-core.kicad_pcb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]
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2025-08-01 Added SC Mixer UI schematics
    [sc-mixer.kicad_sch, sidechain-mixer-core.kicad_pcb, sidechain-mixer-ui.kicad_pcb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]
2025-08-01 Sidechain Mixer UI PCB RC
    [sidechain-mixer-core.kicad_pcb, sidechain-mixer-core.kicad_sch, sidechain-mixer-ui.kicad_pcb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]
2025-08-01 Checked all components on SC-Mixer
    [bom.csv, designators.csv, positions.csv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]
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2025-08-03 ADSR VCA core PCB done
    [adsr-vca-core.kicad_pcb, adsr-vca-core.kicad_sch]
2025-08-03 Designed ADSR VCA UI PCB
    [adsr-vca-core.kicad_pcb, adsr-vca-core.kicad_sch, adsr-vca-ui.kicad_pcb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]
2025-08-06 Updated silkscreen on mixer
    [sidechain-mixer-ui.kicad_pcb]
2025-08-09 Updated sidechain + ADSR PCB
    [adsr-lm324.kicad_sch, adsr-vca-core.kicad_pcb, adsr-vca-core.kicad_sch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]
2025-08-10 Redraw ADSR PCBs to be on top half of the UI
    [adsr-vca-core.kicad_pcb, adsr-vca-ui.kicad_pcb, adsr-vca-ui.kicad_sch]
2025-08-10 ADSR+VCA UI PCB done
    [adsr-vca-ui.kicad_pcb]
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2025-08-10 Removed v0.1 version of ADSR+VCA
    [adsr-lm324.kicad_sch, adsr-vca-core.kicad_pcb, adsr-vca-core.kicad_sch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]
2025-08-10 ADSR+VCA production files ready
    [adsr-lm324.kicad_sch, adsr-vca-core.kicad_pcb, bom.csv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]
2025-08-13 Added double defaults pin row to ADSR
    [adsr-vca-core.kicad_sch, bitcrusher-sh.kicad_sch, lfo.kicad_sch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]
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2025-08-16 Started swapping output and bitcrusher positions
    [bitcrusher-sh.kicad_sch, bom.csv, designators.csv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]
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2025-08-16 Redesigned utils + output UI PCB
    [utils-output-ui.kicad_pcb, utils-output-ui.kicad_sch]
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2025-08-18 ADSR + VCA v0.2
    - The + and - power pins on the VCA op-amp was accidentally swapped. This version fixes it
    [adsr-vca-core.kicad_pcb, audio-cv-in.kicad_sch, bitcrusher-sh.kicad_sch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]
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2025-08-19 Redesigned output module
    - The master volume was _before_ the gain control which made no sense because the volume had an effect on how much signal went into the gain stage. Now the master volume is after the diode limiter/clamper which means the output can be tamed while keeping the overdrive.
    - Rearranged the output resistors so now line out has a 1k resistor.
    - STILL TODO: the headphone output is not protected against accidental +/-12V inputs.
    [output.kicad_sch, utils-output-core.kicad_pcb, utils-output-core.kicad_sch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]
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2025-08-21 Fixed Release pot polarity
    [adsr-vca-ui.kicad_pcb, adsr-vca-ui.kicad_sch, output.kicad_sch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]
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2025-08-23 Replaced THT comps. to SMD on ADSR/VCA
    [adsr-lm324.kicad_sch, adsr-vca-core.kicad_pcb]
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2025-09-09 PSU v0.2 and fixed crosstalk on VCA
    - added PSU v0.2
    - VCA had a crosstalk issue. The input signal got superimposed on the output. The current solution is to move the input voltage divider on the core board as close to the input pin header connection as possible. Additionally, I added the 100k resistor as a THT component to the UI board. Only one of the 100k resistors is needed, but I added both for testing purposes.
    [adsr-vca-core.kicad_pcb, adsr-vca-ui.kicad_pcb, adsr-vca-ui.kicad_sch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]
2025-09-09 Added a note to the VCA board about crosstalk
    [vca.kicad_sch]
2025-09-10 Redesigned VCF PCB to avoid crosstalk
    - There's been quite a bit of crosstalk between the input and output of the VCF module. This PCB design attemtps to separate the input and output so that the crosstalk is minimized.
    [power.kicad_sch, vcf-core.kicad_pcb, vcf-core.kicad_sch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]
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2025-09-11 Fixed DAC SPI bug in BrainSDK
    [brain-core.kicad_sch, mcu.kicad_sch, midi-in.kicad_sch]
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2025-10-25 Swapped DC/DC converter from back to front on PSU PCB
    [psu.kicad_pcb, psu.kicad_sch]
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2025-10-25 Moved LED from ADSR core to UI board
    [adsr-lm324.kicad_sch, adsr-vca-core.kicad_pcb, adsr-vca-core.kicad_sch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]
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2025-10-25 Removed one pot and added one button in Brain
    [brain-core.kicad_pcb, brain-core.kicad_sch, brain-ui.kicad_pcb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]
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2025-11-22 Updated pull-up for MIDI opto in v0.2 Brain
    [brain-core.kicad_pcb, brain-core.kicad_sch, brain-ui.kicad_pcb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]
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
